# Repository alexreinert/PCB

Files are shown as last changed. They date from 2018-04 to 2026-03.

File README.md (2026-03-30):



Dieses Werk ist lizenziert unter einer [Creative Commons Namensnennung - Nicht-kommerziell - Weitergabe unter gleichen Bedingungen 4.0 International Lizenz](http://creativecommons.org/licenses/by-nc-sa/4.0/).

Bei Nutzung der Platinen freue ich mich über Feedback und kleine Aufmerksamkeiten aus meiner [Amazon Wunschliste](https://www.amazon.de/gp/registry/wishlist/3NNUQIQO20AAP/ref=nav_wishlist_lists_1).

Viele Platinen gibt es auch im offiziellen Shop [viopcb](https://www.viopcb.de/).

# PCB
## HB-RF-ETH
Eine Platine um die Homematic Funkmodule HM-MOD-RPI-PCB und RPI-RF-MOD per Netzwerk anschließen zu können.
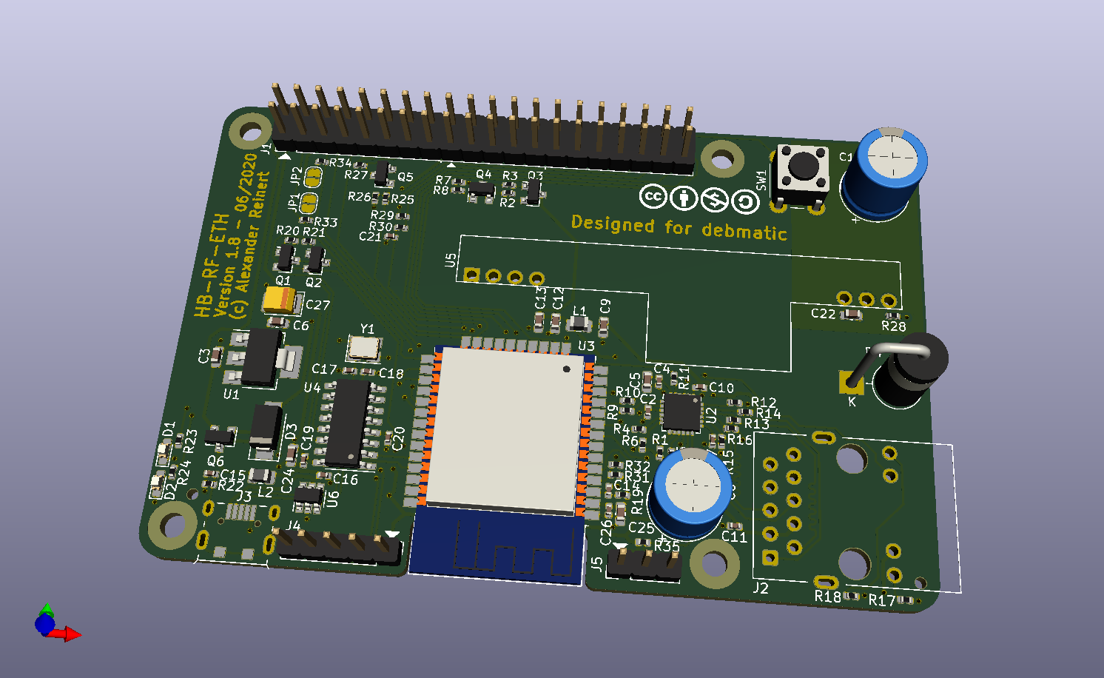
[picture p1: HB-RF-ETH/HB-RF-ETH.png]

[Schaltplan](HB-RF-ETH/HB-RF-ETH.pdf)
Die Platine benötigt spezielle Treiber, welche in [debmatic](https://github.com/alexreinert/debmatic) und in [piVCCU3](https://github.com/alexreinert/piVCCU) verfügbar sind.
Eine passende Firmware findet sich unter [HB-RF-ETH](https://github.com/alexreinert/HB-RF-ETH).
Diese Platine ist auch als fertig bestückter Bausatz erhältlich bei [viopcb](https://www.viopcb.de/produkt/bausatz-hb-rf-eth-mit-poe/).

### Benötigte Bauteile:
Siehe Schaltplan

## HB-RF-USB-2
Eine Platine um die Homematic Funkmodule HM-MOD-RPI-PCB und RPI-RF-MOD per USB anschließen zu können.
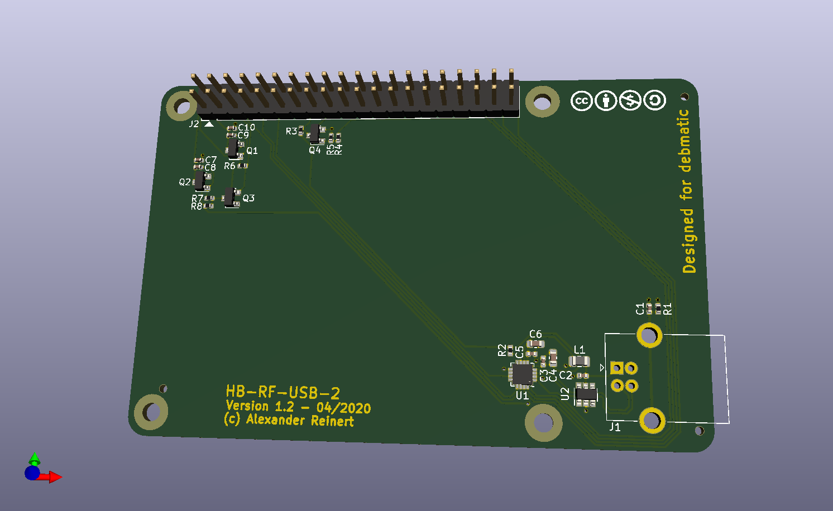
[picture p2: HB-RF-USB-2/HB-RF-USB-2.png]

[Schaltplan](HB-RF-USB-2/HB-RF-USB-2.pdf)
Die Platine benötigt spezielle Treiber, diese sind in [debmatic](https://github.com/alexreinert/debmatic) ab Version 3.51.6-45 und in [piVCCU3](https://github.com/alexreinert/piVCCU) ab Version 3.51.6-40 eingebaut.
Diese Platine ist auch als fertig bestückter Bausatz erhältlich bei [viopcb](https://www.viopcb.de/produkt/bausatz-hb-rf-usb-2/).

### Benötigte Bauteile:
* 1x CP2102N (U1)
* 1x SRV05-4 (U2)
* 2x Kerko 10nF 0402 (C1, C2)
* 6x Kerko 100nF 0402 (C3, C5, C7, C8, C9, C10)
* 2x Kerko 4.7uF 0603 (C4, C6)
* 1x Ferrite Bead 100Ohm, 800mA 0805 (L1)
* 2x AO3401A (Q1, Q2)
* 1x AO3400A (Q3)
* 1x S8050 (Q4)
* 1x Widerstand 1M 0402 (R1)
* 3x Widerstand 1K 0402 (R2, R6, R7)
* 4x Widerstand 10K 0402 (R3, R4, R5, R8)
* 1x USB B Buchse B1HSW6 (J1)
* 1x Pinheader 2x20 (J2)

### EEPROM flashen
[Anleitung](https://hb-programmer.areinert.de)

## HB-RF-USB
Eine Platine um die Homematic Funkmodule HM-MOD-RPI-PCB und RPI-RF-MOD per USB anschließen zu können.
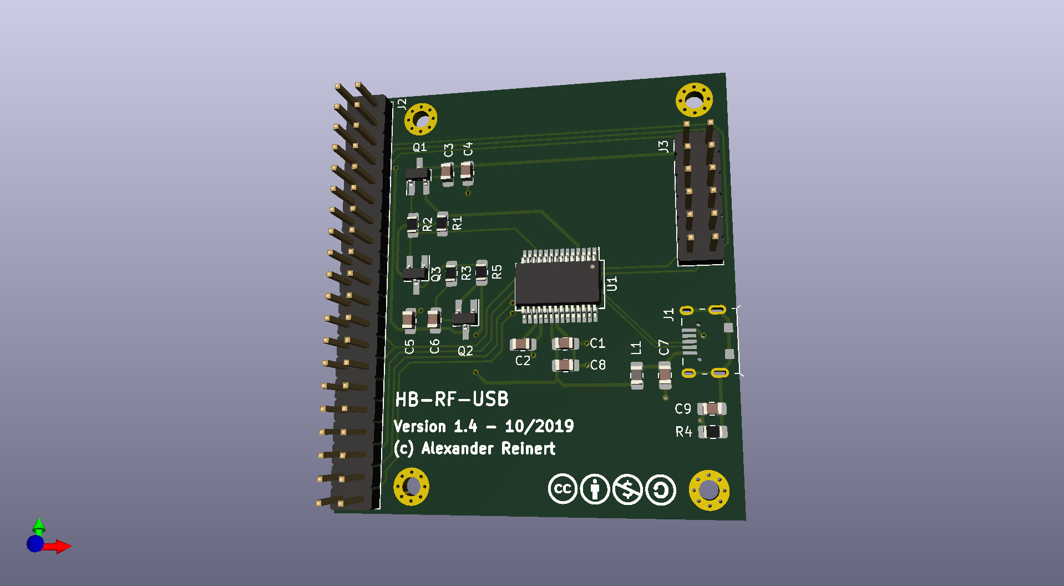
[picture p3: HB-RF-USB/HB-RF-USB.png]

[Schaltplan](HB-RF-USB/HB-RF-USB.pdf)
Die Platine benötigt spezielle Treiber, diese sind in [piVCCU3](https://github.com/alexreinert/piVCCU) ab Version 3.41.11-13, in [debmatic](https://github.com/alexreinert/debmatic) und in [RaspberryMatic](https://github.com/jens-maus/RaspberryMatic) ab Version 3.41.11.20190126 eingebaut.
Diese Platine ist auch erhältlich bei [viopcb](https://www.viopcb.de/produkt/platine-hb-rf-usb/)

### Benötigte Bauteile:
* 1x FTDI FT232RL (U1)
* 1x Micro USB Connector U-F-M5DD-Y-1 (bis Rev. 1.3 MK5P Micro USB Connector)
* 1x Kerko 4.7nF 0805 (C9)
* 1x Kerko 10nF 0805 (C7)
* 6x Kerko 100nF 0805 (C1-C6)
* 1x Kerko 4.7uF 0805 (C8)
* 2x Widerstand 1K 0805 (R2, R3)
* 2x Widerstand 10K 0805 (R1, R5)
* 1x Widerstand 1M 0805 (R4)
* 1x Ferritperle 30 Ohm 0805 (L1)
* 2x IRLML6402 (Q1, Q2)
* 1x IRLML2502 (Q3)
* 1x Pinheader 2*6
* 1x Pinheader 2*20

### EEPROM flashen
[Anleitung](https://hb-programmer.areinert.de)

## HB-UNI-SEN-BATT
Eine universelle Platine für Homebrew Geräte basierend auf [AskSin++ Library](https://github.com/pa-pa/AskSinPP)
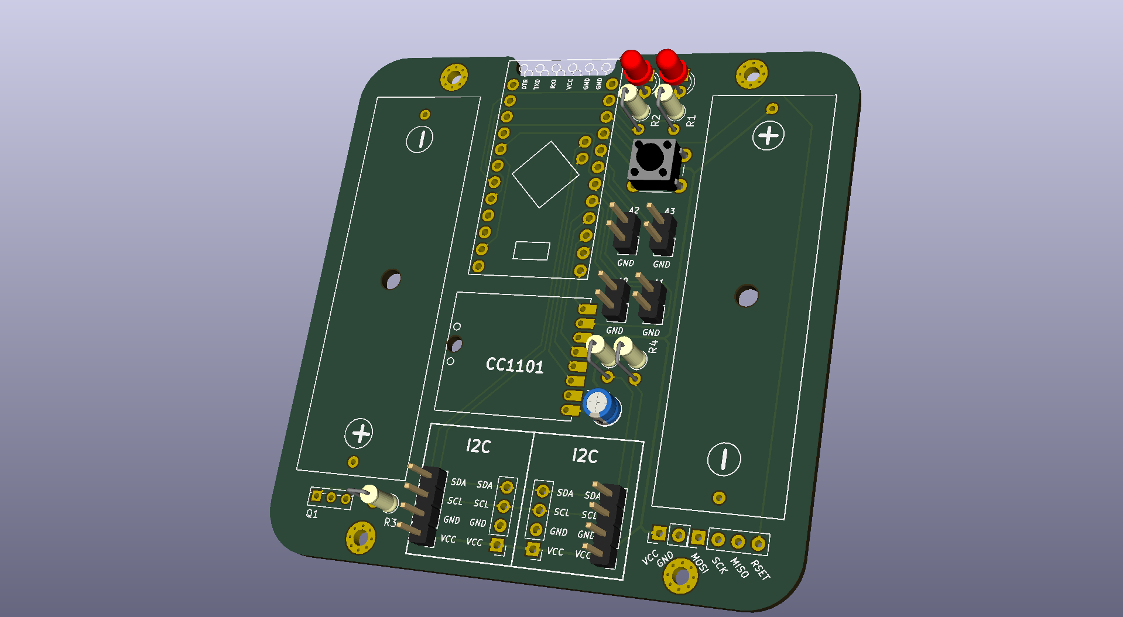
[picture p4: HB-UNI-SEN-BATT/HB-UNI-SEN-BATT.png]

[Schaltplan](HB-UNI-SEN-BATT/HB-UNI-SEN-BATT.pdf)
Diese Platine ist auch erhältlich bei [viopcb](https://www.viopcb.de/produkt/platine-hb-uni-sen-batt/).

### Benötigte Bauteile:
* Arduino Pro Mini 3.3V 8Mhz (The Simple)
* CC1101 Modulplatine 868MHz
* 2x LEDs 3mm Low Current (Pin 4 und 5)
* 2x 470Ohm Widerstände (Vorwiderstand für LEDs)
* Elko 10uF 1,5mm
* 2x Goobay Batteriehalter Mignon Print
* Mikroschalter 6*6mm
* Stiftleiste RM 2mm 1x8 Pin (Für CC1101)
* Stiftleiste RM 2,54MM (nach Bedarf)
* IRLU024N (optional für Verpolungsschutz)
* 100KOhm Widerstand (optional für Verpolungsschutz)
* 2x 10KOhm Widerstand (optional Pullup für I2C)

### Passendes Gehäuse
* Camdenboss CBRS01SWH und CBRS01VWH

### Hinweise
* Achtung: Kein Überspannungschutz vorhanden
* Der Verpolungsschutz ist optional. Dafür Bauteil Q1 (IRLU024N) und R3 (100KOhm Widerstand) bestücken. Alternativ J8 auf der Platinenrückseite brücken um ohne Verpolungsschutz zu arbeiten.

## HB-UNI-SEN-PCB
Eine universelle Platine für Homebrew Geräte basierend auf [AskSin++ Library](https://github.com/pa-pa/AskSinPP)
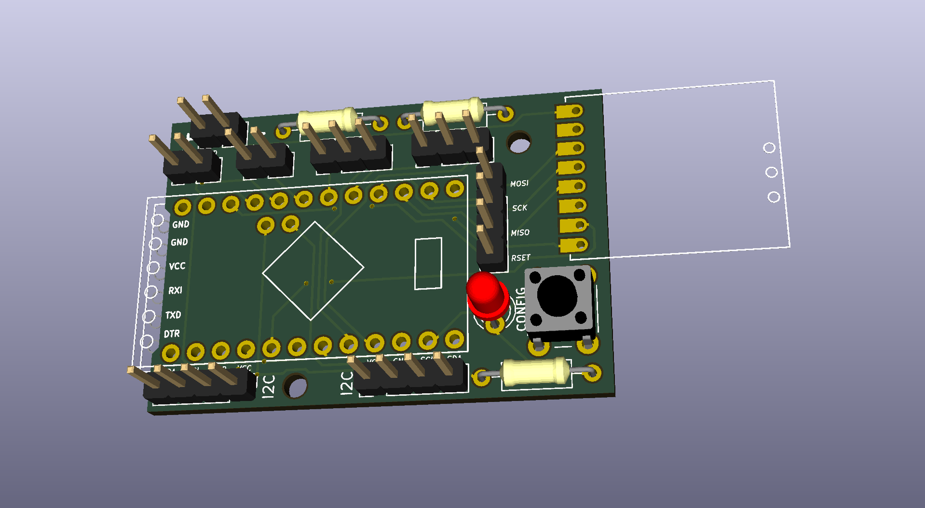
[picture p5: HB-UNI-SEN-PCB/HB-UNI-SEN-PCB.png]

[Schaltplan](HB-UNI-SEN-PCB/HB-UNI-SEN-PCB.pdf)
Diese Platine ist auch erhältlich bei [viopcb](https://www.viopcb.de/produkt/platine-hb-uni-sen-pcb/).

### Benötigte Bauteile:
* Arduino Pro Mini 3.3V 8Mhz (The Simple)
* CC1101 Modulplatine 868MHz
* 1x LEDs 3mm Low Current (Pin 4)
* 1x 470Ohm Widerstände (Vorwiderstand für LEDs)
* Mikroschalter 6*6mm
* Stiftleiste RM 2mm 1x8 Pin (Für CC1101)
* Stiftleiste RM 2,54MM (nach Bedarf)
* Optional: 2x 10KOhm Widerstand und 2x 10KOhm PTC (Temperaturmessung mit PTC an A0 und A1)

### Hinweise
* Achtung: kein Verpolungs- oder Überspannungschutz vorhanden
* Am I2C sind keine Pullups vorhanden, da diese im Regelfall auf I2C Platinen bereits integriert sind
* Aktuell fehlt noch ein Kondensator am VCC vom CC1101.

## HB-UNI-644 (Rev. 2)
Eine universelle Platine für Homebrew Geräte basierend auf [AskSin++ Library](https://github.com/pa-pa/AskSinPP) und dem ATmega644PA
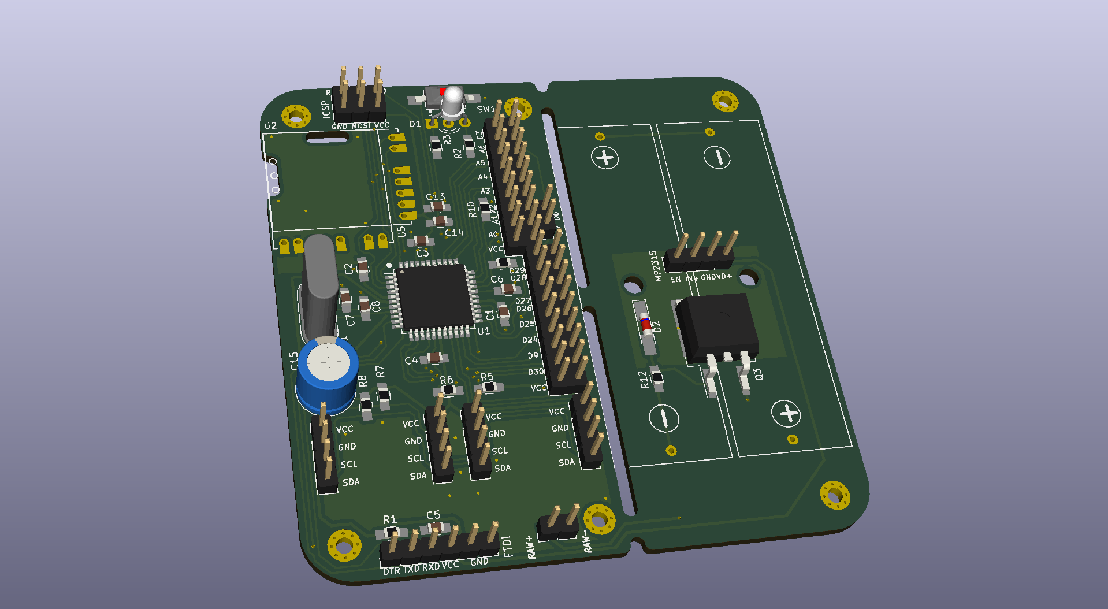
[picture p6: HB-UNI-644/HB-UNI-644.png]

[Schaltplan](HB-UNI-644/HB-UNI-644.pdf)
Diese Platine ist auch erhältlich bei [viopcb](https://www.viopcb.de/produkt/platine-hb-uni-644-rev-2/).

### Benötigte Bauteile:
#### Grundfunktion
* ATmega644PA oder ATmega1284P (TQFP44) (U1)
* CC1101 Modulplatine 868MHz ggf. mit RM 2.0 Pinheader (U2)
* 1x Kerko 10uF 0805 (C13)
* 7x Kerko 100nF 0805 (C1-C6, C14)
* 2x Widerstand 330 Ohm 0805 (R2, R3)
* 1x Widerstand 10K Ohm 0805 (R1)
* 1x Triple Color LED Common Cathode THT (D1)
* 1x Tactile Switch 2 Pin 6x3.5 SMD (SW1)
* 1x Quarz 8 Mhz HC49 THT (Y1) (optional)
* 2x Kerko 22pF 0805 (C7, C8) (optional für Quarz)
* Pinheader nach Bedarf

#### Power Option 1: Batteriebetrieb mit Step-Up
* 2x Goobay Batteriehalter Mignon Print
* 1x Widerstand 470K Ohm 0805 (R5)
* 1x Widerstand 100K Ohm 0805 (R6)
* 1x MAX1724EZK33 (U3)
* 1x LQH43CN100K03L (L1)
* 1x Kerko 10uF 0805 (C9)
* 1x Kerko 33uF 1206 (C10)
##### Verpolungsschutz und Überlastschutz
* 1x IRLML6244 (Q1)
* 1x Widerstand 100K Ohm 0805 (R4)
* 1x PTC 6V/250mA 1206 (F1)

#### Power Option 2: Externe Stromversorgung mit 5-9V, 100mA
* 1x HT-7533-1 (U4)
* 1x Kerko 10uF 50V 1206 (C11)
* 1x Kerko 10uF 0805 (C12)
* 1x Elko 1000uF 8mm*12mm (C15)
##### Verpolungsschutz und Überlastschutz
* 1x IRLML5203 (Q2)
* 1x Widerstand 100K Ohm 0805 (R11)
* 1x PTC 16V/250mA 1206 (F1)

#### Power Option 3: Externe Stromversorgung 5-24V, 1A
* 1x [MP2315 Power Module](https://de.aliexpress.com/item/DC-DC-R-cktritt-Abw-rtswandler-Einstellbar-4-5-V-24-V-zu-5-V-3A/32833398745.html)
   Kontakt zum Trimmer durchtrennen, Lötbrücke bei 3.3V anbringen
* 1x Elko 1000uF 8mm*12mm (C15)
##### Verpolungsschutz und Überlastschutz
* 1x IRF4905S (Q3)
* 1x Widerstand 100K Ohm 0805 (R12)
* 1x Zener 16V MiniMelf (D2)
* 1x PTC 30V/2A 1206 (F1)

#### I2C Pullup Widerstände (optional)
* 2x Widerstand 10k Ohm 0805 (R7, R8)

#### Vorwiderstände für NTC Messung an A0 und A1
* 2x Widerstand 10k Ohm 0805 (R9, R10)

### Passendes Gehäuse
* Camdenboss CBRS01SWH und CBRS01VWH

### Betrieb mit 5V, 16MHz bei Netzbetrieb
* Der MC kann auch mit 5V und dann mit 16MHz betrieben werden, dafür müssen ggü. oben folgende Anpassungen gemacht werden:
* Nicht möglich bei Power Option 1
* Bei Power Option 2: HT-7550-1 statt HT-7533-1 uf U4, Eingangsspannung >= 6V
* Bei Power Option 3: Lötbrücke auf MP2315 Modul bei 5V statt bei 3.3V, Eingangsspannung >= 6V
* CC1101 auf Position U5 statt auf U2
* Nicht bestücken: C13, C14
* Quarz Y1 mit 16MHz statt 8MHz
* Zusätzliche Bauteile
   * 1x LM-3480-3.3 (U6)
   * 1x TXS0108EPWR (U7)
   * 3x Kerko 10uF 0805 (C16, C18, C19)
   * 3x Kerko 100nF 0805 (C17, C20, C21)
* ACHTUNG: Alle VCC Pins laufen dann auf 5V, auch z.B. die vom I2C

### Hinweise
* Auch wenn die meisten Bauteile SMD sind, so ist die Platine für Handlötung entwickelt. Dementsprechend sind alle Teile mind. 0805 mit vergrößerten Pads für Handlötung.
* Es darf immer nur eine Power Option genutzt und bestückt werden
* Die rechte Seite der Platine kann entfernt werden, wenn die Batteriehalter oder das MP2315 Power Module nicht benötigt werden, es laufen keine Leiterbahnen rechts der Fräsung (abgesehen von denen für die Batterie bzw. Power Module)
* Die Lötbrücke J2 muss immer geschlossen werden, außer es wird der Verpolungsschutz für Batteriebetrieb verwendet
* Falls eine externe Spannung von 3.3V ohne Spannungsanpassung, Verpolungsschutz und Überlastschutz verwendet werden soll, dann muss die Lötbrücke J4 geschlossen werden
* Die Anschlüsse an J9 sind zusammen mit J12 genau passend für die Platine CJMCU-2803 um an den Anschlüssen ein Darlington Array zu verwenden (Jeder der Ports ist dann mit 500mA belastbar)
* Beschriftung der Anschlüsse folgt dem Bobuino Pinout

## HB-UNI-SEN-WEA
Eine passende Platine für den [Wettersensor von Jérôme](https://github.com/jp112sdl/HB-UNI-Sen-WEA/)
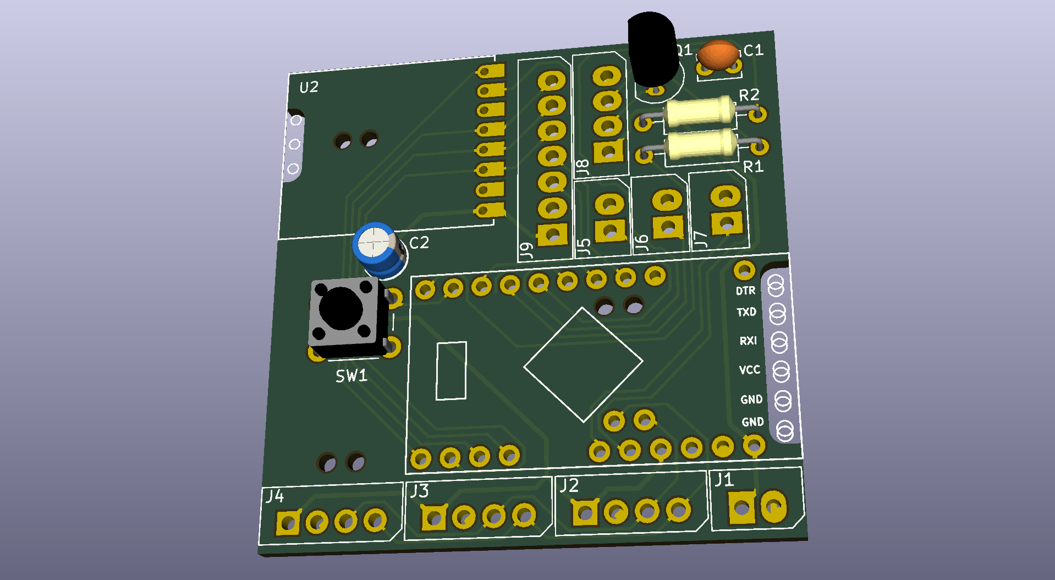
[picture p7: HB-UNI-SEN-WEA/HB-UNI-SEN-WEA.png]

[Schaltplan](HB-UNI-SEN-WEA/HB-UNI-SEN-WEA.pdf)
Diese Platine ist auch erhältlich bei [viopcb](https://www.viopcb.de/produkt/platine-hb-uni-sen-wea/).

### Benötigte Bauteile:
* Arduino Pro Mini 3.3V 8Mhz (The Simple)
* CC1101 Modulplatine 868MHz
* Elko 10uF 1,5mm
* Mikroschalter 6*6mm
* Kerko 1nf RM 2.5mm
* 10K Widerstand
* 100K Widerstand
* MPSA13 TO-92
* 4x Molex Spox 2-pol (Alternativ Stiftleiste oder Kabel direkt anlöten)
* 4x Molex Spox 4-pol (Alternativ Stiftleiste oder Kabel direkt anlöten)
* 1x Molex Spox 7-pol (Alternativ Stiftleiste oder Kabel direkt anlöten)
* Stiftleiste RM 2mm 1x8 Pin (Für CC1101)

### Hinweise
* Achtung: kein Verpolungs- oder Überspannungschutz vorhanden
* Am I2C sind keine Pullups vorhanden, da diese im Regelfall auf I2C Platinen bereits integriert sind

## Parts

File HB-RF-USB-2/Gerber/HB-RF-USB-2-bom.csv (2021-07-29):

Comment | Designator | Footprint | LCSC
10nF | C2,C1 | Capacitor_SMD:C_0402_1005Metric | C15195
4.7uF | C6,C4 | Capacitor_SMD:C_0603_1608Metric | C19666
100nF | C8,C7,C9,C10,C5,C3 | Capacitor_SMD:C_0402_1005Metric | C1525
USB_B | J1 | Connector_USB:USB_B_OST_USB-B1HSxx_Horizontal
Conn_02x20_Odd_Even | J2 | Connector_PinHeader_2.54mm:PinHeader_2x20_P2.54mm_Vertical
Ferrite Bead | L1 | Inductor_SMD:L_0805_2012Metric | C1015
AO3401A | Q2,Q1 | Package_TO_SOT_SMD:SOT-23 | C15127
AO3400A | Q3 | Package_TO_SOT_SMD:SOT-23 | C20917
S8050 | Q4 | Package_TO_SOT_SMD:SOT-23 | C2146
1M | R1 | Resistor_SMD:R_0402_1005Metric | C26083
1K | R7,R6,R2 | Resistor_SMD:R_0402_1005Metric | C11702
10K | R8,R4,R5,R3 | Resistor_SMD:R_0402_1005Metric | C25744
CP2102N | U1 | Package_DFN_QFN:SiliconLabs_QFN-20-1EP_3x3mm_P0.5mm | C89049
SRV05-4 | U2 | Package_TO_SOT_SMD:SOT-23-6 | C85364

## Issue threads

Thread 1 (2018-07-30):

Elko für HB-UNI-SEN-PCB

Hasenpups, 2018-07-30:
Hallo,

Im Schaltplan ist ein 10µF Kondensator eingezeichnet und in der Übersicht schreibst du: Elko 100uF 1,5mm
Was empfiehlst du denn? Hast du vielleicht einen Link für einen passenden Kondensator, ich konnte jetzt keinen mit 1,5mm RM finden.

Danke
Stefan

Closed 2018-07-30.

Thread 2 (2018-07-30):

HB-UNI-SEN-BATT

Hasenpups, 2018-07-30:
Hallo,

Leider sind 3 Leiterbahnen vom CC1101 mit der Massefläche auf der Rückseite der Platine verbunden. Dadurch kann der CC1101 nicht richtig vom Arduino angesprochen werden.
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

Ich denke der Fehler ist passiert als du unten die Pins für das flashen des Bootloaders hinzugefügt hast.

alexreinert, 2018-07-30:
Hhm, ich habe die Platinen hier liegen und da ist das nicht der Fall. Auch die Lötstoppfreistellung zwischen den Pins vom Arduino sieht sehr befremdlich aus und das habe ich so noch nie gesehen. Ich fürchte fast, dass da mit git irgendwas falsch zusammengemerged wurde. Schau ich mir mal an, sobalb ich wieder an meinem Rechner bin.

Hasenpups, 2018-07-30:
Hab die Dateien mal bei dirtypcb und jlcpcb rendern lassen. Sieht bei beiden identisch aus.
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
Ich hab die Bahnen jetzt mal mit einem Cuttermesser getrennt und jetzt kann auch der CC1101 und der BME280 korrekt angesprochen werden.

Closed 2018-07-30.

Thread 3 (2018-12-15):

Platine kaufen

capitaenz, 2018-12-15:
Hallo Alex,

kann man die Platine (HB-UNI-SEN-BATT) von dir irgendwo kaufen? Und wenn ja zu welchem Preis?

VG
Leif

alexreinert, 2018-12-15:
Meld dich per Mail bei mir: alex@areinert.de

Vg Alex

Closed 2018-12-15.

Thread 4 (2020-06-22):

Info bzgl. weitere Platinen

LeelooDallas-github, 2020-06-22:
Wow, schöne Sachen die Du hier gebaut hast.
Ggf. ist in dieser Ecke auch was für Dich dabei.
https://forum.fhem.de/index.php/topic,73954.0.html

CU Leeloo

alexreinert, 2020-06-22:
Danke für die Info, die sind mir bereits bekannt. Das hier ist einfach die Sammlung meiner Platinen und erhebt nicht den Anspruch einer Übersicht aller für HM verfügbaren Platinen, wie sie z.B. auf asksinpp.de gepflegt wird.

Closed 2020-06-22.

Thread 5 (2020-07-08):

HB-RF-USB-2 question

KrX3D, 2020-07-08:
hello,

i have got an HM-MOD-RPI-PCB , can i also use it on my nas where i have unraid running and iobroker in docker? or can it only be run with raspberry?

alexreinert, 2020-07-08:
This is just a pcb. If piVCCU or debmatic and the matching kernel are running on your nas, depends on your nas, but you gave no information about it.

KrX3D, 2020-07-09:
hi, my nas (hardware) is self made. and it is running unraid:

https://unraid.net/

if im not mistaken its linux based.
on it im running several docker images like iobroker etc.

do you know it it is possible to run piVCCU or debmatic with an docker image or virtual machine?

thanks in advance

alexreinert, 2020-07-09:
Docker is not supported, as there is the need to load and access special kernel modules, which is not possible inside a docker container.
(Real) VMs like kvm are supported. piVCCU does only support ARM/ARM64 hardware, debmatic support both x64 and ARM.

KrX3D, 2020-07-09:
ok thanks for the info, if i get it running somehow i will post it here, so others can profit from it.

Closed 2020-07-20.

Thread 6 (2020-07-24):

Clarification: Ferrite Bead

dersimn, 2020-07-24:
> - 1x Ferrite Bead 100Ohm, 800mA 0805 (L1)

Really 100 Ω? Not 100 *m*Ω?
Can you recommend a specific part? Maybe from Reichelt, Aliexpress, Farnell?

alexreinert, 2020-07-24:
100 Ohm is correct. This is not the DC resistance, it is the resistence for high frequencies. A possible part would be https://m.de.aliexpress.com/item/4000444822616.html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

dersimn, 2020-07-25:
Ah, yeah makes sense. Thank you!

Closed 2020-07-25.

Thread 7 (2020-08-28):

Reset vs. ^Reset

dersimn, 2020-08-28:
Wieso erhalten beide Aufsteckboards (HM-MOD-RPI-PCB und RPI-RF-MOD) bei der **HB-RF-USB** das selbe Signal (jeweils Pin 12, 35) während das Signal bei der **HB-RF-USB-2** invertiert wird?

## HB-RF-USB
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

## HB-RF-USB-2
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

alexreinert, 2020-08-28:
Das RPI-RF-MOD invertiert das Reset Signal. Das ist mir bei der HB-RF-USB aber erst aufgefallen, nachdem ich den ersten Hardware Prototypen hatte. Der FT232RL bei der HB-RF-USB kann aber im Zustand Floating bleiben, in welchem sowohl das RPI-RF-MOD, als auch das HM-MOD-RPI-PCB die Reset Leitung selbständig in den richtigen Zustand ziehen um nicht im Reset zu sein. Zum Reseten kann man aber einfach einmal kurz auf High und auf Low gehen und danach wieder auf Floating und damit können beide Module zuverlässig resettet werden.
Der CP2102N vom HB-RF-USB-2 kann nicht in den Zustand Floating gebracht werden, daher muss für eines der beiden Module eine Invertierung vorgenommen werden und doppelte Invertierung für das RPI-RF-MOD fand ich doof, so dass jetzt beide Module einmal invertiert werden.

Closed 2020-08-28.

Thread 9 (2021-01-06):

Is HB-RF-USB-2 compatible with RaspberryMatic?

Denis1983, 2021-01-06:
Hello,

HB-RF-USB is compatible with RaspberryMatic, but HB-RF-USB-2?
Is the driver included in RaspberryMatic?

Regards,
Denis

alexreinert, 2021-01-06:
This is not the RaspberryMatic issue tracker.

Closed 2021-01-06.

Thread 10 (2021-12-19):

LEDs with HM-MOD-UART

frank-f, 2021-12-19:
Hi!

I'm trying to design a PCB based on your HB-RF-USB. I don't need compatibility with RPI-RF-MOD and I want to achieve a more compact form factor. What I would be interested in is the three LEDs of RPI-RF-MOD. As far as I understand, I could just add a few LEDs to my board, right? All I'd need to know is, if they're connected to VCC or Ground on the other side. Unfortunately in all RPI-RF-MOD pictures I could find the area is covered by a sticker, so I don't know where the traces end. Also looking at the FT232RL template was no help, since these lines are configured as I/O. Can you tell me how to connect the LEDs?
Also while looking over closed issues here, I found that the reset line should have been inverted - would it make sense to do that in my board or would that break compatibility with the driver you're using in piVCCU?

Thank you!

frank-f, 2021-12-21:
I dug further and I think the FTDI chip is pulling the lines low to enable the LEDs. Can you confirm that?

I still don't know if I should adapt the inverted RESET line.

alexreinert, 2021-12-21:
Your idea will not work as rhe LEDs are only driven if there is a RPI-RF-MOD is available.
Regarding the form factor: Maybe the HmIP-RFUSB (Non Telekom version) would be the right solution for you, it has now support for BidCos/HmIP dual mode, too.
If you proseed with your own pcb, please use a different USB ID, the USB ID in the template is registered to me and dedicated for my PCB.

frank-f, 2021-12-21:
Too bad about the LEDs. I didn't know about HmIP-RFUSB yet. It does look interesting - if it can do HM and HMIP, the difference to my own PCB would just be an SMA connector. Maybe I'll pursue in that direction.
In case I'll have a PCB produced, would piVCCU even still recognize when using a different USB ID?

alexreinert, 2021-12-21:
The HmIP-RFUSB was only able to communicate using HmIP until the last month. But eQ-3 released a new firmware, that supports both, HM (BidCos) and HmIP. Support for that is included in the current piVCCU testing release, which will hopefully be released as stable in the next days. Soldering a pigtail with SMA connector to it, is possible, too. (Of course you loose the original CE certification and guarantee in that case)
The different USB ID would not be recognized. But I can add the USB ID to the kernel modules, if you are respect the license of the HB-RF-USB and publish the PCB under CC BY-NC-SA 4.0 license.

frank-f, 2021-12-21:
> Soldering a pigtail with SMA connector to it, is possible, too. (Of course you loose the original CE certification and guarantee in that case)

Well my current solution is a modified HM-MOD-UART as well. I guess, I don't have any warranty on that either. 😇
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

> The different USB ID would not be recognized. But I can add the USB ID to the kernel modules, if you are respect the license of the HB-RF-USB and publish the PCB under CC BY-NC-SA 4.0 license.

That would be awesome. Could you also enable the LEDs for that USB ID or is that more complicated?
Of course, the source files will be published under the same license - wether I'll have it produced in the end or not.

alexreinert, 2021-12-21:
Yes, this more complicated, as this is partly in the closed source binaries of eQ-3.

frank-f, 2021-12-21:
Ah, too bad. I'll keep them in the board schematic, but leave them unpopulated then. Or maybe I'll use them as RXLED and TXLED or something.

frank-f, 2022-01-26:
> The different USB ID would not be recognized. But I can add the USB ID to the kernel modules, if you are respect the license of the HB-RF-USB and publish the PCB under CC BY-NC-SA 4.0 license.

It took a little while longer because I was waiting on the USB PID, some parts and also I first started designing it into an 1551USB3 case, but then noticed that it should also fit into a smaller version.

I am not sure if all (or any?) of the mosfets are needed. I think, two were not needed for my project, so I left those out. I kept the one that seems to switch the HM-MOD-UART 3.3V line on and off. Does it work like that with your driver?

I named it [HM-1551USB2](https://github.com/frank-f/HM-1551USB2).

frank-f, 2022-04-01:
@alexreinert I decided to order a small batch of my PCBs. Can you add my VID/PID to piVCCU or can easily I do that myself somehow? I'd like to test if my design working. Thank you in advance. :)

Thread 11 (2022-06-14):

Synology DSM 7.1-42661 lässt den Zugriff aus einer VM auf das Modul per USB nicht mehr zu

Schlumpel, 2022-06-14:
Habe den HB-RF-USB-TK an einer Raspberrymatic-OVA als Virtuelle Maschine sauber betreiben können. Seit DSM 7.1-42661 weigert sich die Raspberrymatic mit angestecktem Modul zu starten, bei einem Start der VM mit abgezogenem Modul klappt der Start, beim nachträglichen Einstecken und Aktivieren des Moduls passiert aber nichts mehr...
Bin ratlos. Der Synology Support ist angeschrieben, lässt aber noch auf sich warten.

Danke für Unterstützung

alexreinert, 2022-06-15:
Sorry, ich kann weder für Synology, noch für RaspberryMatic, noch für die kommerzielle Version der Platine Support leisten.
Im Zweifel im RaspberryMatic Github ein Issue aufmachen oder im Homematic Forum nachfragen, ob jemand eine Idee hat.

Closed 2022-06-15.

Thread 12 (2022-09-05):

HB-RF-USB / 0x6F70 unter Windows erneut flashen ?

Newbie-2, 2022-09-05:
Unter Windows wird die Hardware als HB-RF-USB / Port_#0005.Hub_#0002 erkannt.

Aber die Software "FT_Prog" findet den FTDI232 nun nicht mehr, da es ja für das Gerät idProduct: 0x6F70 keinen Windows lizensierten Treiber gibt !

Ein manuelles ändern des Treibers führt zu der Fehlermeldung: "der hashwert für die datei in der angegebenen katalogdatei nicht vorhanden"

Wie kann ich den FTDI232 unter Windows erneut flashen ?

alexreinert, 2022-09-05:
Man kann die Platine unter Windows nicht neu flashen und ich seheauch keinen Grund dafür. Sollte der Flash seine Daten verlieren, dann muss man von einem Totalschaden ausgehen, das ist mir aber bisher noch nie untergekommen.

Newbie-2, 2022-09-05:
Das klingt ja nicht so gut.
Wenn nicht unter Windows, ist den ein erneutes flashen unter Linux möglich ?

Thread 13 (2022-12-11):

Stromverbrauch HB-RF-USB-2

T1mey, 2022-12-11:
Hallo, gibt es Infos wie hoch der zusätzliche Stromverbrauch der Platine ist?

alexreinert, 2022-12-11:
je nach aufgestecktem Funkmodul zwischen 10 und 15mA.

T1mey, 2022-12-11:
Liegen da 5V an ?

Eigentlich simple Frage ..  lohnt es sich ein pi3 abzuschalten und auf einen futro s740 mit HB-RF-USB-2 umzuziehen (den futro setze ich gerade auf) und will nicht unbedingt 2 systeme laufen lassen ...

alexreinert, 2022-12-11:
Die Platine hat die vollständige Beschaltung um ein HM-MOD-RPI-PCB oder ein RPI-RF-MOD per USB anzuschließen und mit debmatic oder piVCCU auf den jeweils unterstützten Platformen zu betreiben. Beim RPI--RF-MOD darf kein externenes Netzteil genutzt werden.
Siehe einfach auch die Vorstellung der Platine im Homematic Forum.

Ob es sich lohnt, muss man selbst entscheiden, auf jeden Fall braucht die Platine deutlich weniger Strom als ein Pi.

Closed 2023-01-09.

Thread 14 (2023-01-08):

HB-RF-USB2 together with SONOFF Zigbee 3.0 Module makes the USB stack go nuts

luzifer84, 2023-01-08:
Hello Alex,
I have a Linux system with Kernel 5.15.0-051500rc7-generic x86_64 up and running where I have OpenHab 3.2 running in a VirtualBox, Homematic - to be more precise debmatic - in another one with a HB-RF-USB2 connected to it. This has been running for quite a while now (okay, Kernel got an update recently). And according to the rule - never change a running system - I decided to get rid of all the Zigbee control units as I did with the Homematic CCU and bought this USB devices (https://www.ebay.de/itm/384875702899?var=652772510813) as suggested to be the best in several forums. Now the trouble began.
When I plugged it in everything at first seemed to work fine. But when I did a reboot all USB devices except the USB hubs vanished from lsusb. dmesg showed up some random disconnects every second for the HB-RF-USB2 device. So I decided to unplug it. All other devices came back to lsbusb. Then I plugged it in again. Everything worked fine. I did this again inluding the reboot. Same behaviour.
When I unplug the SONOFF during the boot - everything is fine.

When everything is plugged in after the boot has finished it looks like this:
Bus 004 Device 003: ID 05e3:0612 Genesys Logic, Inc. Hub
Bus 004 Device 002: ID 0b95:1790 ASIX Electronics Corp. AX88179 Gigabit Ethernet
Bus 004 Device 001: ID 1d6b:0003 Linux Foundation 3.0 root hub
Bus 003 Device 003: ID 8087:0029 Intel Corp. AX200 Bluetooth
Bus 003 Device 006: ID 10c4:ea60 Silicon Labs CP210x UART Bridge --> the SONOFF
Bus 003 Device 005: ID 0403:6f70 Future Technology Devices International, Ltd HB-RF-USB
Bus 003 Device 004: ID 0001:0000 Fry's Electronics MEC0003
Bus 003 Device 002: ID 05e3:0610 Genesys Logic, Inc. Hub
Bus 003 Device 001: ID 1d6b:0002 Linux Foundation 2.0 root hub
Bus 002 Device 001: ID 1d6b:0003 Linux Foundation 3.0 root hub
Bus 001 Device 001: ID 1d6b:0002 Linux Foundation 2.0 root hub

I neither do have any experience whether this configurations works stable over time nor do I have any clue how to get rid of this boot problem. Do you have any suggestions how I could solve this?

Thanks for your time and help in advance.

Greetings,
Torben

luzifer84, 2023-01-09:
Hi,
I just wanted to add some additional pieces of information.
Having both devices plugged in at the same time, devices stop working after a few minutes. I receive the following messages in the host:

Jan  9 05:03:58 firetux-nuc kernel: [21317.321071] usb 3-5-port2: disabled by hub (EMI?), re-enabling...
Jan  9 05:03:58 firetux-nuc kernel: [21317.321467] usb 3-5.2: USB disconnect, device number 5
Jan  9 05:03:58 firetux-nuc kernel: [21317.545497] usb 3-5.2: new full-speed USB device number 7 using xhci_hcd
Jan  9 05:03:58 firetux-nuc kernel: [21317.653805] usb 3-5.2: New USB device found, idVendor=0403, idProduct=6f70, bcdDevice= 6.00
Jan  9 05:03:58 firetux-nuc kernel: [21317.653827] usb 3-5.2: New USB device strings: Mfr=1, Product=2, SerialNumber=3
Jan  9 05:03:58 firetux-nuc kernel: [21317.653837] usb 3-5.2: Product: HB-RF-USB
Jan  9 05:03:58 firetux-nuc kernel: [21317.653843] usb 3-5.2: Manufacturer: Alexander Reinert
Jan  9 05:03:58 firetux-nuc kernel: [21317.653850] usb 3-5.2: SerialNumber: A94YTFKB
Jan  9 05:03:58 firetux-nuc kernel: [21317.969837] usb 3-5.2: reset full-speed USB device number 7 using xhci_hcd
Jan  9 05:03:59 firetux-nuc kernel: [21318.285897] usb 3-5.2: reset full-speed USB device number 7 using xhci_hcd
Jan  9 05:09:34 firetux-nuc kernel: [21654.217259] usb 3-5-port1: disabled by hub (EMI?), re-enabling...
Jan  9 05:09:34 firetux-nuc kernel: [21654.217705] usb 3-5.1: USB disconnect, device number 4
Jan  9 05:09:35 firetux-nuc kernel: [21654.452226] usb 3-5.1: new low-speed USB device number 8 using xhci_hcd
Jan  9 05:09:35 firetux-nuc kernel: [21654.557363] usb 3-5.1: New USB device found, idVendor=0001, idProduct=0000, bcdDevice= 1.00
Jan  9 05:09:35 firetux-nuc kernel: [21654.557370] usb 3-5.1: New USB device strings: Mfr=1, Product=2, SerialNumber=0
Jan  9 05:09:35 firetux-nuc kernel: [21654.557373] usb 3-5.1: Product: MEC0003
Jan  9 05:09:35 firetux-nuc kernel: [21654.557374] usb 3-5.1: Manufacturer: MEC
Jan  9 05:09:35 firetux-nuc kernel: [21654.579145] hid-generic 0003:0001:0000.0002: hiddev0,hidraw0: USB HID v1.00 Device [MEC MEC0003] on usb-0000:00:14.0-5.1/input0
Jan  9 05:09:35 firetux-nuc kernel: [21654.580077] usb 3-5-port2: disabled by hub (EMI?), re-enabling...
Jan  9 05:09:35 firetux-nuc kernel: [21654.580602] usb 3-5.2: USB disconnect, device number 7
Jan  9 05:09:35 firetux-nuc kernel: [21654.804380] usb 3-5.2: new full-speed USB device number 9 using xhci_hcd
Jan  9 05:09:35 firetux-nuc kernel: [21654.912697] usb 3-5.2: New USB device found, idVendor=0403, idProduct=6f70, bcdDevice= 6.00
Jan  9 05:09:35 firetux-nuc kernel: [21654.912721] usb 3-5.2: New USB device strings: Mfr=1, Product=2, SerialNumber=3
Jan  9 05:09:35 firetux-nuc kernel: [21654.912730] usb 3-5.2: Product: HB-RF-USB
Jan  9 05:09:35 firetux-nuc kernel: [21654.912737] usb 3-5.2: Manufacturer: Alexander Reinert
Jan  9 05:09:35 firetux-nuc kernel: [21654.912744] usb 3-5.2: SerialNumber: A94YTFKB
Jan  9 05:09:35 firetux-nuc kernel: [21655.236797] usb 3-5.2: reset full-speed USB device number 9 using xhci_hcd
Jan  9 05:09:36 firetux-nuc kernel: [21655.548702] usb 3-5.2: reset full-speed USB device number 9 using xhci_hcd

Plus these mesages I saw multiple times:
module: x86/modules: Skipping invalid relocation target, existing value is nonzero for type 1, log 8e0437ee, val ffffffffc145fade

alexreinert, 2023-01-09:
Both devices are on the same internal USB Controller (Bus 3). Try on different USB Controllers. Could be an issue with to high power consumption if both sticks are used on a single controller.

luzifer84, 2023-01-09:
I tried but no different result. In fact the last configuration with both devices at the same controller is a configuration where I put both even on an external USB HUB with external 5V 1A power supply. Did not make any difference.

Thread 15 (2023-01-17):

Modul wird nach Neustart nicht erkannt (Stromversorgung?)

DasPflanze, 2023-01-17:
Hallo Herr Reinert,

erstmal vielen Dank für die Entwicklung der verschiedenen Platinen! Allerdings habe ich mit meiner ein kleines Problem. Nach der Erstinstallation funktionierte alles ohne Probleme. Bis zum ersten Neustart meines Servers (Unraid mit RaspberryMatic als VM).

Die Platine wird danach noch korrekt unter lsusb erkannt nur leider bekommt das Modul keinen Strom mehr. An Pin 1 (von der 40 Pin Leiste) liegen dann statt 3,3V nur zwischen 1 und 2V an. Misst man Pin 2, so fängt er meist bei ca. 2,2V an und dann sinkt der Wert relativ zügig bis auf 0V (vermutlich ein Kondensator der sich entlädt). Solange Pin 2 nicht auf 0V ist wird die Platine nicht erkannt. Erst bei 0V und nach einem Neustart der VM lässt sich das Modul wieder nutzen.

Um Probleme mit der VM auszuschließen habe ich das selbe auch an einem Raspberry Pi 4 versucht mit dem selben Ergebnis.

Mein Bauchgefühl sagt mir, dass hier eventuell ein Widerstand (o.ä.) defekt ist. Können Sie da weiterhelfen?

Grüße
Stefan Müller

alexreinert, 2023-01-17:
Sorry, ich kann keinen wirklichen Support für RaspberryMatic geben, da die Implementierung dort nicht der Referenzimplementierung entspricht.
Da es nicht mal eine Angabe gibt, um welche Platine es überhaupt geht, kann ich auch keinen Tipp in Richtung der Lösung geben.

DasPflanze, 2023-01-17:
Ah sorry, das habe ich komplett vergessen...
Es geht um die HB-RF-USB-2 und ich denke nicht, dass es mit RaspberryMatic zusammenhängt. Theoretisch sollte das Modul ja 5V bekommen, selbst wenn man das USB Kabel nur in ein USB-Netzteil Steckt, oder?

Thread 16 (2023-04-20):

HB-RF-USB-2 wird heiß und disconnected mit over-current-condition

viennaa, 2023-04-20:
Hi Alex,

ich wollte mein HB-RF-USB mit dem HB-RF-USB-2 ersetzen. Ich betreibe es mit dem RPI-RF-MOD and einem Intel NUC.

Wenn ich die Platine anstecke, ohne den RPI-RF-MOD verbunden zu haben, wird der Treiber erkannt und alles ist in Ordnung.
Sobald ich sie mit dem RPI-RF-MOD verbunden anstecke, habe ich ständige disconnects im Linux und die Platine wird innerhalb weniger Sekunden sehr warm. Ich habe sie nach ca. 10 Sekunden abgesteckt, damit sie nicht durchbrennt.

```
[756009.049042] usb usb2-port1: over-current condition
[756009.182377] usb 2-2: USB disconnect, device number 97
[756009.439048] usb 2-2: new full-speed USB device number 98 using xhci_hcd
[756009.580818] usb 2-2: New USB device found, idVendor=10c4, idProduct=8c07, bcdDevice= 2.00
[756009.580832] usb 2-2: New USB device strings: Mfr=1, Product=2, SerialNumber=3
[756009.580838] usb 2-2: Product: HB-RF-USB-2
[756009.580843] usb 2-2: Manufacturer: Alexander Reinert
[756009.580847] usb 2-2: SerialNumber: ***
[756009.715710] usb usb2-port1: over-current condition
[756009.849104] usb 2-2: USB disconnect, device number 98
[756010.105747] usb 2-2: new full-speed USB device number 99 using xhci_hcd
[756010.247789] usb 2-2: New USB device found, idVendor=10c4, idProduct=8c07, bcdDevice= 2.00
[756010.247803] usb 2-2: New USB device strings: Mfr=1, Product=2, SerialNumber=3
[756010.247809] usb 2-2: Product: HB-RF-USB-2
[756010.247813] usb 2-2: Manufacturer: Alexander Reinert
[756010.247817] usb 2-2: SerialNumber: ***
```

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

Habe ich eine defekte Platine erhalten oder was mache ich falsch? Ich kann auch keine verbundenen Pins o.Ä. auf der Platine erkennen.

VG

alexreinert, 2023-04-20:
Es ist hoffentlich kein Netzteil am RPI-RF-MOD eingesteckt? Wobei das das Problem erklären könnte, weil da dann u.U. Ströme mit mehreren Ampere fließen könnten.
Ansonsten sieht das schwer nach einem Kurzschluß aus ohne, dass ich ohne Messung sagen könnte, ob dieser auf dem RPI-RF-MOD oder der HB-RF-USB-2 ist, oder ob das Funkmodul nicht korrekt aufgesetzt ist und dadurch eine Verbindung zwischen VCC und Gnd herstellt (komplett falsch rum,  oder um einige Pins verschoben).

Closed 2023-04-20.

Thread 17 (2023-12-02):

HB-RF-ETH nicht mehr erreichbar

vore, 2023-12-02:
Hallo Herr Reinert,

ich habe mir vor einger Zeit die Platine HB-RF-ETH mit POE gekauft. Lag jetzt etwas länger in der Schublade weil ich passende Infrastruktur noch nicht fertig hatte. Jetzt bin ich soweit, aber die Platine ist nicht mehr ansprechebar. Der ESP scheint zu booten (LED grün leuchtet nach kurzer Zeit) an der Steckbuchse leuchtet aber nur eine LED (vermutlich POE).
Hatte beim Kauf die Platine testweise angeschlossen, Firmwareupdates eingespielt und dann erst mal wieder verpackt und zur Seite gelegt, die Funktion war auf jeden Fall gegeben.
Auch ein Werksreset hilft nicht, die Platine ist nicht erreichbar.

Könnte eventuell das Steckmodul defekt sein? POE funktionioniert aber anscheinend noch.
Kann ich etwas prüfen und ggf. tauschen?

Danke!
Grüße  Volker Reinhardt

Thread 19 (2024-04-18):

HB-RF-USB-2 verstorben?

DarthDestroyer, 2024-04-18:
Schönen guten Abend,

ich habe seit August 2021 die HB-RF-USB-2 in Kombination mit dem RPI-RF-MOD erfolgreich betrieben. Alles lief, bis auf Startschwierigkeiten (war wohl nicht geflashed von Smartkram), bisher ohne Auffälligkeiten.

Damals hatte ich mir mit
```
systemctl stop debmatic
detect_radio_module --debug /dev/raw-uart
java -Dgnu.io.rxtx.SerialPorts=/dev/raw-uart -jar /opt/HmIP/hmip-copro-update.jar -p /dev/raw-uart -o -f /firmware/RPI-RF-MOD/dualcopro_update_blhmip-4.2.14.eq3
detect_radio_module --debug /dev/raw-uart
```
helfen können.

Jetzt läuft aber gar nichts mehr! Per USB kommt nur noch Käse, sowohl unter Linux als auch Windows wird rein gar nichts erkannt (Windows steigt aus mit "Fehler bei Identifizierung") und Debian (mit installiertem Debmatic) mit
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

Ist jetzt ein Auszug aus dem dmesg...
RPI-RF-MOD leuchtet "weiß" - Meiner Einschätzung nach

Die Linux Umgebung ist ein Proxmox mit USB Controller komplett durchgeschliffen (PCI) und vorher "nur" mit Port USB Passthrough getestet - Keine Unterschiede!

Unter lsusb nicht aufgelistet...

Kabel hab ich mehrere durch...

Hat ja auch vorher alles einwandfrei funktioniert! Ist im Rack verbaut, die Kombi - Da ist auch nichts mit Runterfallen oder Erschütterung!

Genutzt, hatte ich die Geschichte über Rapsberrymatic als Home-Assistant Addon - ob jetzt Raspberrymatic ein Firmwareupdate "versucht" hat und dabei verkackt hat - weiß ich nicht... Wenn die Hardware nicht verstorben ist, dürfte dies der andere Schuldige sein!

Kann ich noch etwas prüfen oder versuchen?

Vielen Dank und Grüße gehen raus!

alexreinert, 2024-04-19:
Die Meldungen aus dmesg sehen extrem nach Hardware Problem aus. Nachdem das Kabel bereits getauscht wurde, würde ich mal einen kritischen Blick auf die Lötstellen der USB Buchse schauen.

DarthDestroyer, 2024-04-20:
Alles nachgelötet - Lötstellen aus der Hölle aber die Messwerte sahen gut aus!
Danke nochmal, dass du auch die Schaltpläne zur Verfügung stellst - Das hat zum Nachmessen super geholfen!

Auch die Gegenstelle auf dem RPI-RF-MOD nachgelötet...

Leider brachte alles keinen Erfolg:
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

Was ich beim letzten Test jetzt erkannte, die LED blinkt mehrmals kurz rot ca. 5 mal in sehr kurzen Intervallen um anschließend dann (eher) weiß stehen zu bleiben...

Ich vermute, da ist nur noch das Grab zu schaufeln?
Spannung scheint durchzugehen - Sonst würde der RPI-RF-MOD ja gar nichts tun...

alexreinert, 2024-04-20:
Klingt dann leider wirklich nach einem Hardware Defekt.

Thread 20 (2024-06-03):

HB-RF-ETH piVCCU

tonreg44, 2024-06-03:
Ich möchte Homematic in der Synology integrieren und habe mir den kompletten Bausatz gekauft und installiert Ich erreiche die Platine über die iP Adresse, weiß aber nicht wie ich piVCCU installieren kann. Wenn ich mit putty versuche bekomme ich Network error: connection refused. Ich verwende Port 22 und SSH. Was mache ich falsch??

alexreinert, 2024-06-03:
Die Platine ist dafür gedacht um mit ihr ein Funkmodul per Netzwerk an eine piVCCU oder debmatic Installation anzuschließen. Auf ihr selbst kann man kein piVCCU installieren.

tonreg44, 2024-06-08:
ich habe exakt diesen Bausatz. Wird das Funkmodule über die untere Platine mit Strom versorgt?
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

alexreinert, 2024-06-08:
PoE, Micro USB oder über den Anschluss am Funkmodul. Wichtig ist aber, das nur eine der drei Möglichkeiten genutzt wird, da es sonst zu Schäden kommen kann.

tonreg44, 2024-06-10:
Ich muss etwas ausholen um mein Projekt zu beschreiben. Ich habe eine seit langer Zeit laufende Homematik Steuerung mit Raspberry PI und CCU3, läuft seit Jahren, Ziel ist aber homematic auf meiner Synology einzurichten. Dazu habe ich den oben gezeigten Bausatz gekauft. Vorgegengen bin ich nach dem YouTube von Stefan (verdrahtet). Soweit ist alles installiert (Redmatic OVA). Was ich nicht zum Laufen bekomme ist die Verbindung über USB zur Synology. Wenn ich Geräte anlernen möchte erscheint diese Nachricht:
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. Auf das Funkmodule kann ich zugreifen
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
Hier ist der Zusammenbau beschrieben: https://technikkram.net/blog/2020/08/17/endlich-verfuegbar-neue-platine-hb-rf-eth-zusammenbau-und-einrichtung/. Mir ist nicht klar, wie ich das piVCCU image auf die Synology bekomme. Desweiteren kann ich die geforderte "Zusatzsoftware für den HB-RF-ETH support" über putty nicht installieren (sudo apt install hb-rf-eth). Es erscheint diese Nachricht:
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
Für die Unterstützung schon im voraus besten Dank.

alexreinert, 2024-06-10:
Anschluss per USB geht mit der HB-RF-ETH gar nicht, es geht nur die Nutzung per Netzwerk. Es gibt kein Image von piVCCU für die Synology. Das Paket hb-rf-eth muss man auf dem System installieren, auf dem piVCCU (oder debmatic) läuft, nicht auf der HB-RF-ETH Platine. Diese hat keinen Zugang per SSH, sondern nur die Weboberfläche und für die technische Anbindung des Funkmoduls an die Treiber auf der piVCCU/debmatic Installation.

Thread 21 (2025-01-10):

HB-RF-USB-2 wird erkannt / Funkmodul aber nicht

Fepsi91, 2025-01-10:
Hallo,

ich wollte mit meiner Raspberrymatic von einem PI3 auf eine VM auf einem Windows PC wechseln.
Da ich für meine Hausautomatisierung sowieso einen Mini-PC betreibe, liegt es nah auch alle Module hier laufen zu lassen.

Ich habe die VM nach der Anleitung eingerichtet. Nun wird aber das Funkmodul nicht erkannt. Unter lsusb wird der HB-RF-USB-2 auch angezeigt.
Wenn ich das ganze an der PI3 anschließe funktioniert das Funkmodul wie gewünscht.
Ich bin absoluter Linux Neuling, und daher für jede Hilfe dankbar.

Vielen Dank im Voraus !

alexreinert, 2025-01-11:
Sorry, aber für RaspberryMatic kann ich leider keinen Support geben. Bitte dort fragen.

Rossi0209, 2025-01-11:
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

Moin, Du musst natürlich im Hypervisor (keine Ahnung welcher das bei Dir ist, vermutlich VM Workstation oder Proxmox - wäre auch eine hilfreiche Info), den Adapter an die VM hängen.

Ich mache den Virtualisierungskram beruflich mit vielen tausenden Maschinen, woher sollte wohl eine Maschine wissen, dass der Adapter für genau diese Maschine ist?

Schau mal in die Einstellungen der VM (evtl. runterfahren), da gibt es garantiert irgendwo Hardwareeinstellungen wie HDDs, RAM … da ist auch irgendwo USB, ggf. gibt es da auch irgendwo einen Button wo man neue Hardware hinzufügen kann.

Von der Performance wird das aber glaube ich eng auf einem MiniPc. Wenn man das sowieso schon virtualisiert, würde ich zudem auch ein Debian nehmen.

Hoffe das hilft.

Viele Grüße
Marcus

Fepsi91, 2025-01-11:
Moin,

ich arbeite beruflich auch mir Virtualisierungsumgebungen. Bin dann tiefergehend aber eher im SPS Bereich unterwegs.
Die Hardware wird automatisch beim Startup an die VM durchgereicht. In VM-Ware wird das ganz auch als aktiv mit der VM verbunden angezeigt.
Nur bin ich jetzt nicht so bewand in der Raspberrymatic um tiefergehend zu suchen warum hier das Funkmodul nicht erkannt wird.
Hier ein paar Screenshots:
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

Danke für die schnelle Hilfe!

Gruß
Fabian

Rossi0209, 2025-01-11:
Siehst Du denn den Menüpunkt  bzgl. Led?

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

Fepsi91, 2025-01-11:
Ja, den Menüpunkt habe ich

Rossi0209, 2025-01-11:
Dann sollte das Modul doch auch eigentlich erkannt worden sein.

Fepsi91, 2025-01-11:
Leider nicht.

hier noch die Info aus der Raspberrymatic
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

Und auch wenn ich Geräte anlernen möchte kommt ein Hinweis, dass kein Modul erkannt wurde.

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

charlie89, 2025-09-30:
@Fepsi91: Probier doch mal einen USB-Hub zwischen PC und HB-RF-USB-2 zu stecken. Ist egal ob es ein 15 Jahre alter USB 2.0 Hub oder so ein neuer USB-Dongle ist, der aus USB-C mehrere USB-Ports inkl. SD-Kartenleser und HDMI-Ausgang macht.

Denn ich hatte (bis gestern) auf einem Supermicro H12SSL Mainboard auch genau das Problem, dass die HB-RF-USB-2 Platine per lsusb sichtbar war, aber dann von Raspberrymatic nicht erkannt wurde.
Ein `detect_radio_module --debug /dev/raw-uart` hat bei mir gezeigt, dass es Daten sendet aber keine Daten zurückkommen, obwohl grundsätzlich die USB-Verbindung geht. Mit einem USB-Hub dazwischen (sowohl alt als neu) funktionierte es sofort, d.h. der USB-Controller am Mainboard hat da irgendeine Inkompatibilität mit dem HB-RF-USB-2 und hat die Daten einfach verschluckt. Und das Problem tritt auf allen 4 USB-Ports auf dem Mainboard auf, obwohl 2 Ports direkt in die CPU gehen und 2 Ports über einen ASM1042 USB->PCIe Controller angebunden sind.
Die USB-Hubs dürften weniger Bugs haben als die in Mainboard/CPU verbauten USB-Controller...

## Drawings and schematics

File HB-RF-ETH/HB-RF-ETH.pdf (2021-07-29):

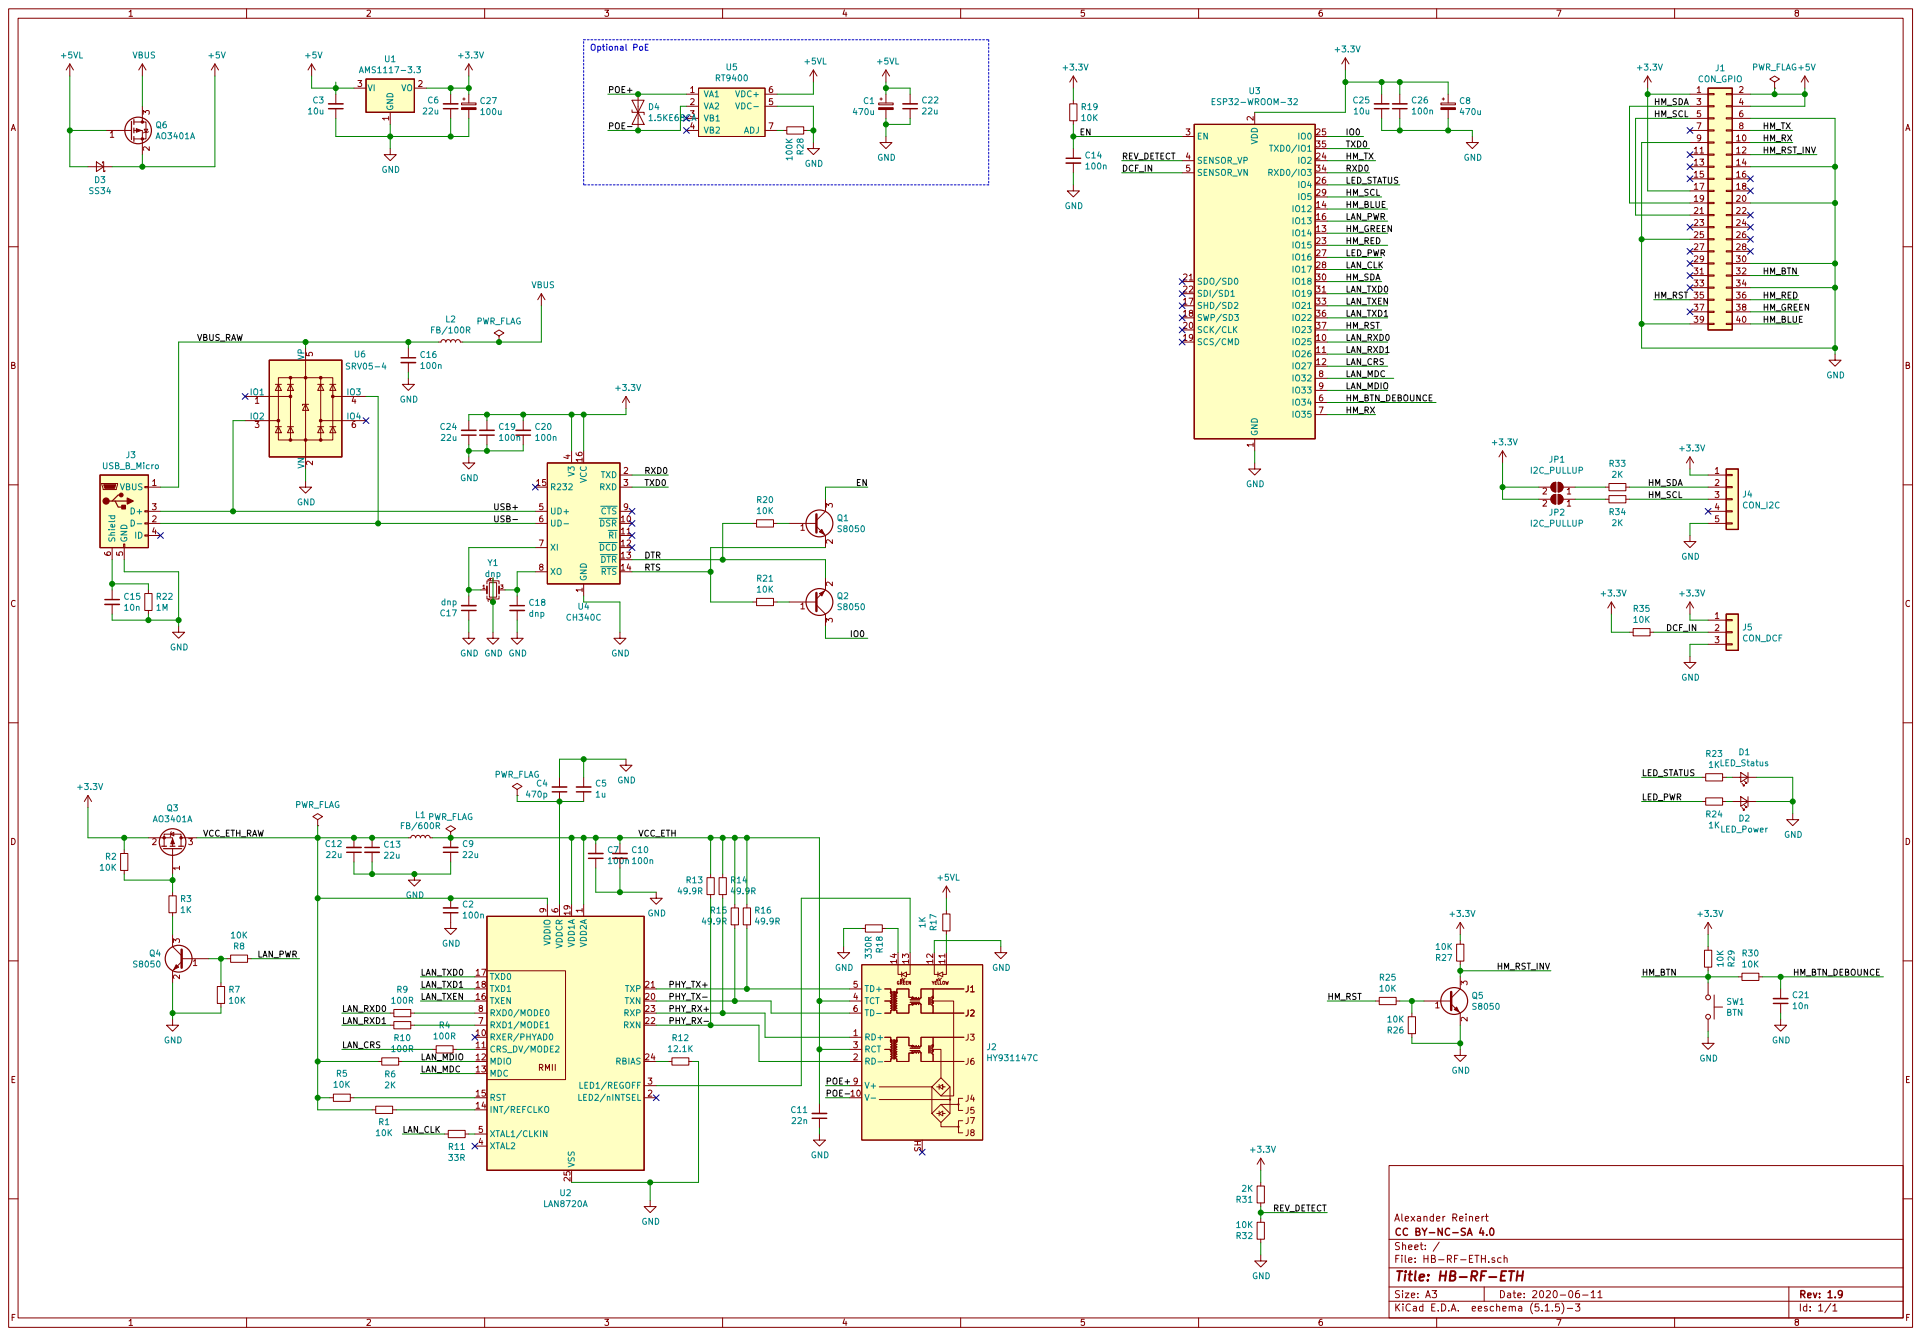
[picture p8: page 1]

2 SCK/CLK 20 SDO/SD0 21 SDI/SD1 22
HM_TX HM_RX HM_RST

21 | 22
23 | 24

1 DSR 10 RI 11 DCD 12 DTR 13 RTS 14 R232 15 VCC 16 TXD 2 RXD 3 V3

4 UD+ 5 UD- 6 XI 7 XO 8 CTS 9 U4 CH340C

File: HB-RF-ETH.sch Sheet: / CC BY-NC-SA 4.0 Alexander Reinert

Id: 1/1 Title: HB-RF-ETH

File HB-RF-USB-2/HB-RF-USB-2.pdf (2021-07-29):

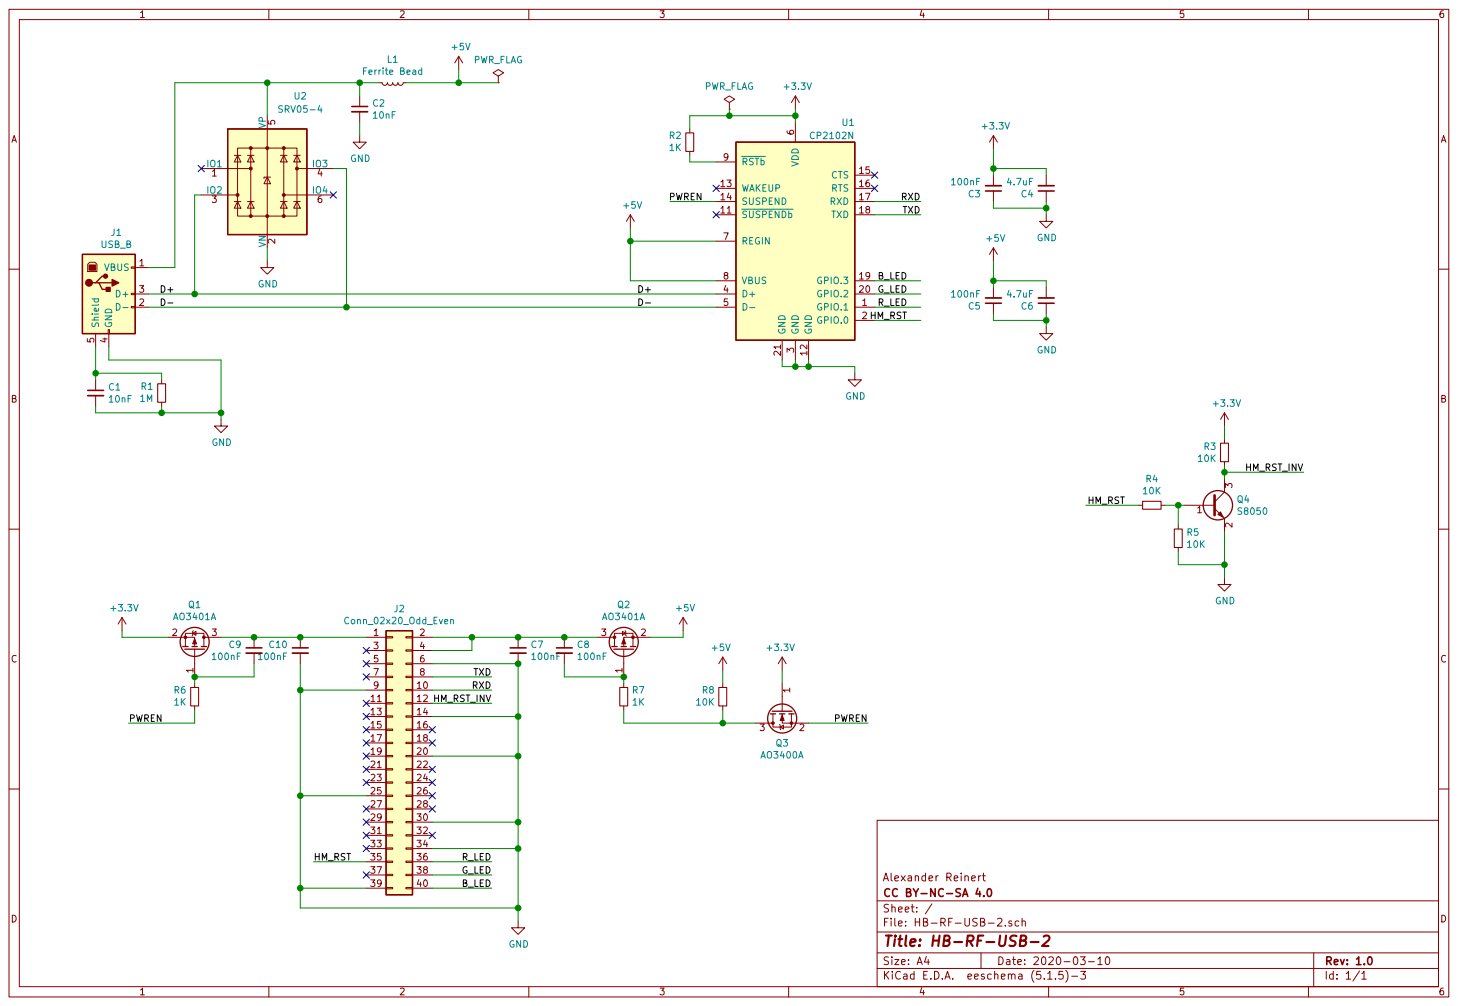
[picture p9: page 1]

File: HB-RF-USB-2.sch Sheet: / CC BY-NC-SA 4.0 Alexander Reinert R7

Id: 1/1 Title: HB-RF-USB-2

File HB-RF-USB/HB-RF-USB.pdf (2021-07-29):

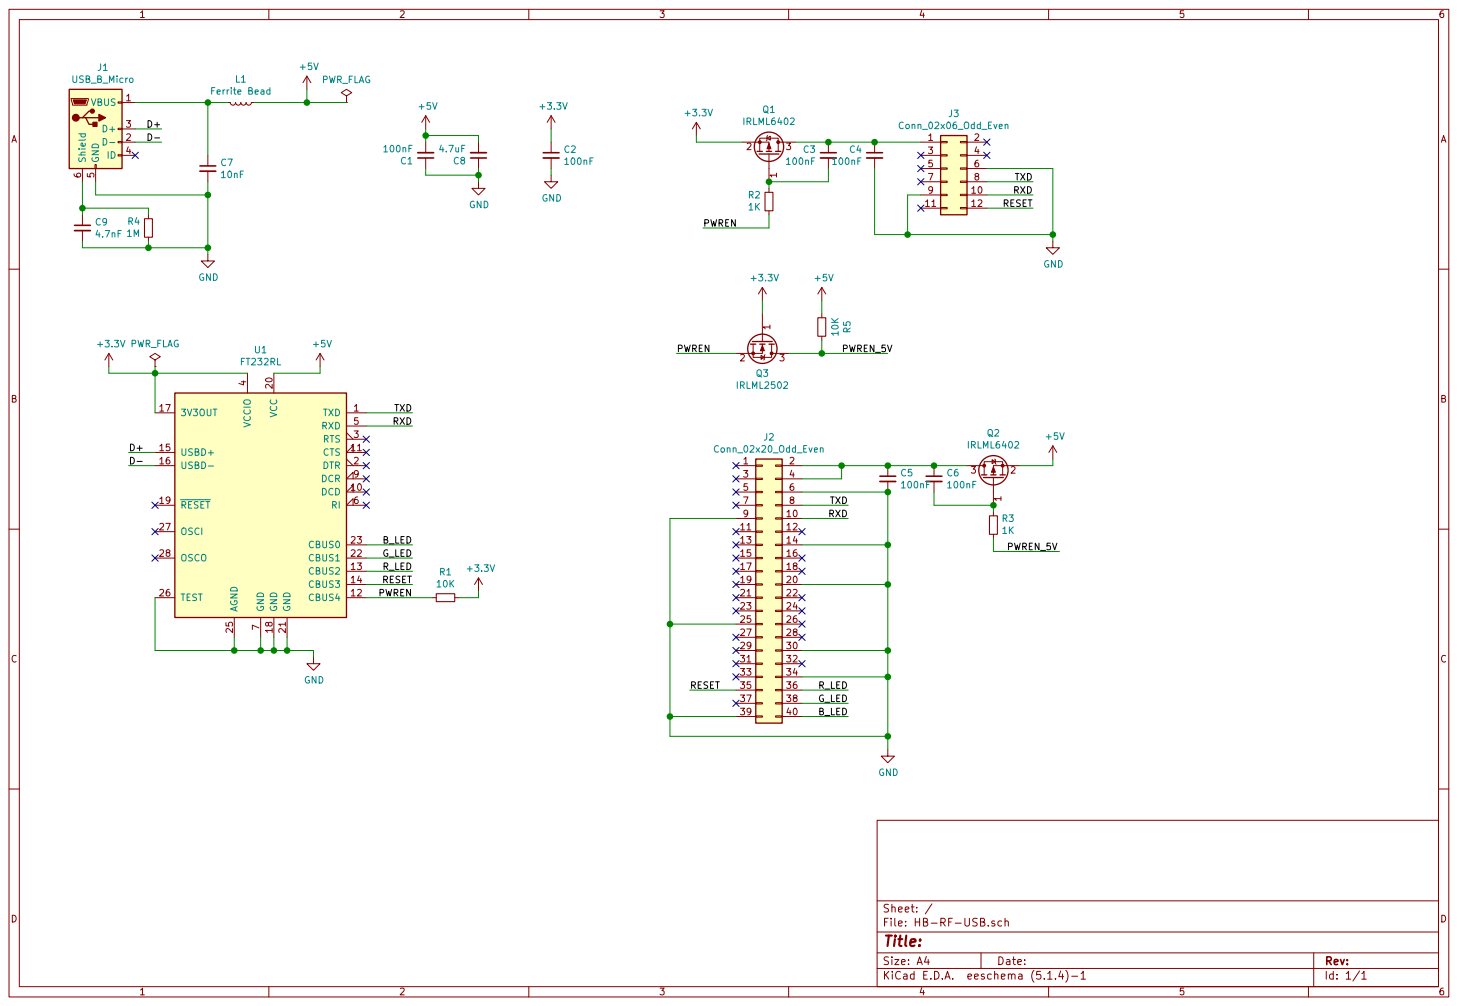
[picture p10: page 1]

Id: 1/1 Title: File: HB-RF-USB.sch Sheet: /

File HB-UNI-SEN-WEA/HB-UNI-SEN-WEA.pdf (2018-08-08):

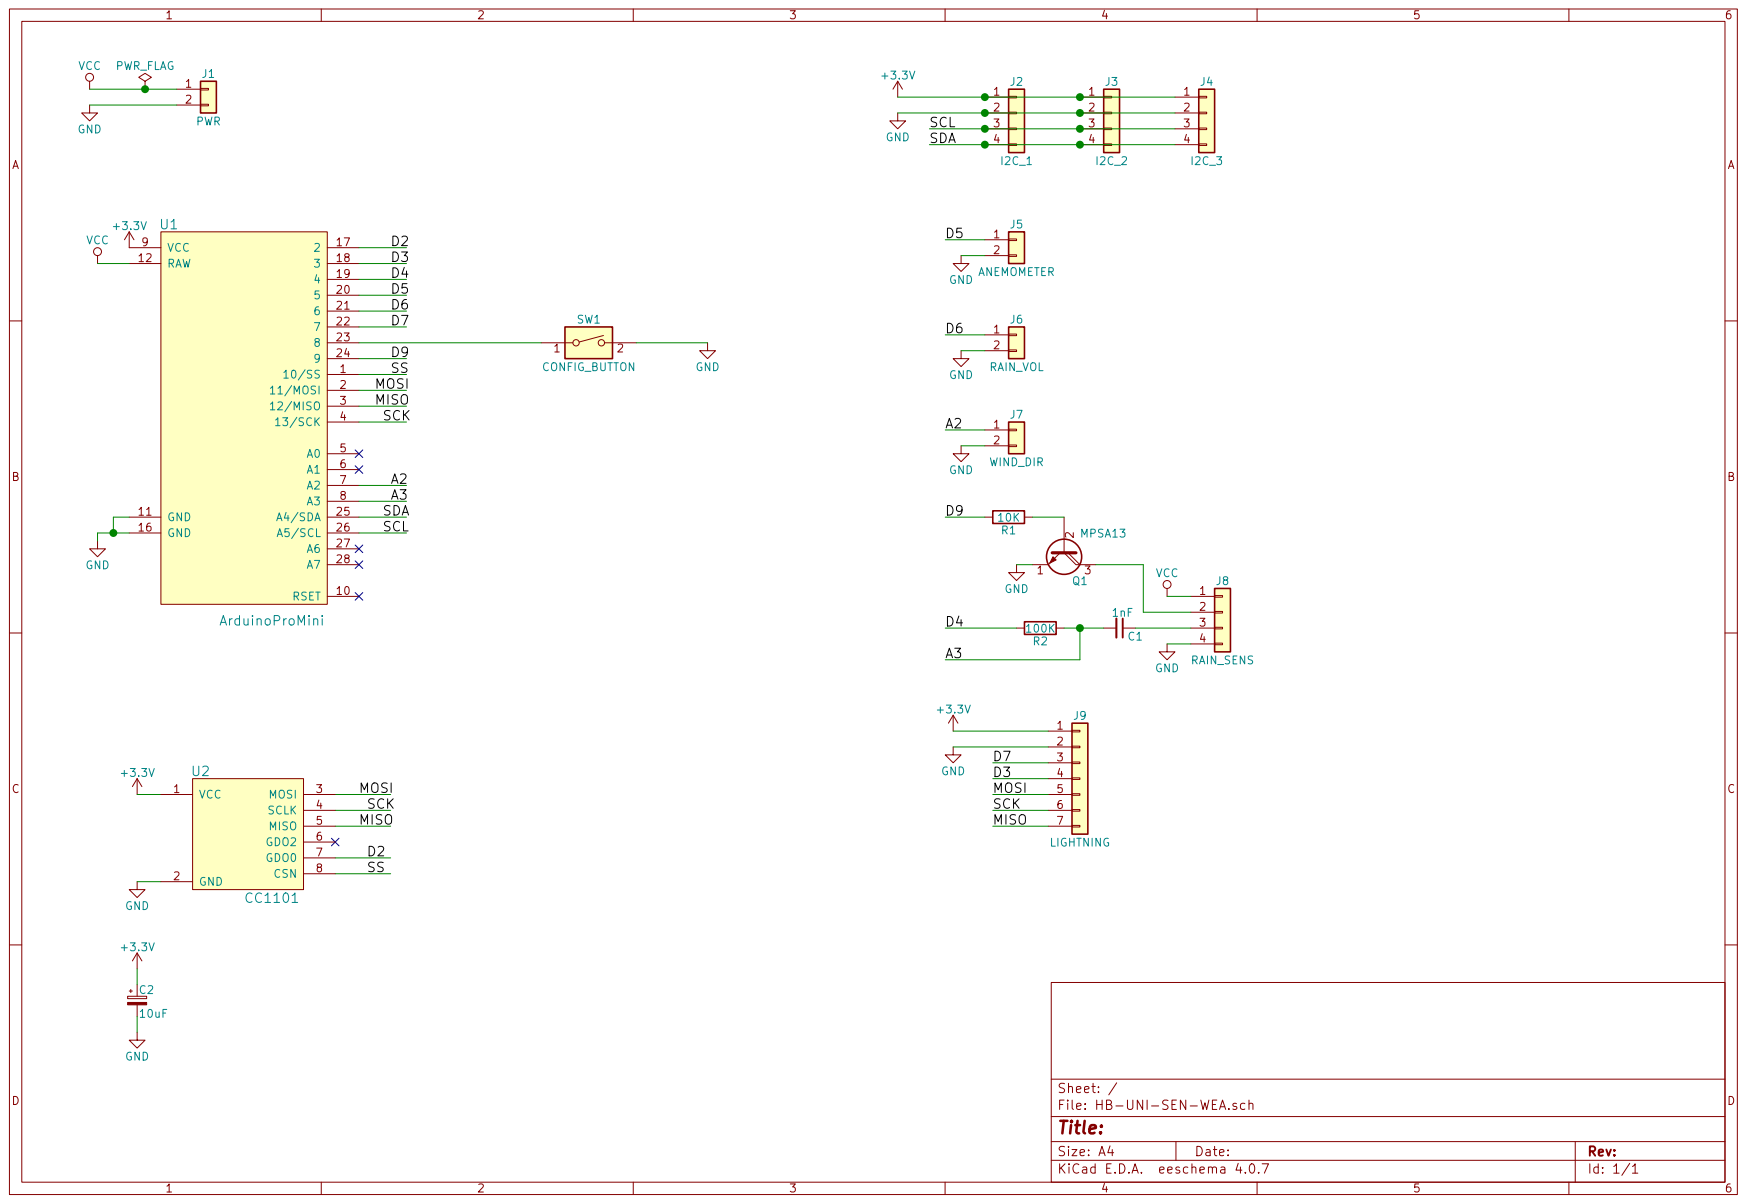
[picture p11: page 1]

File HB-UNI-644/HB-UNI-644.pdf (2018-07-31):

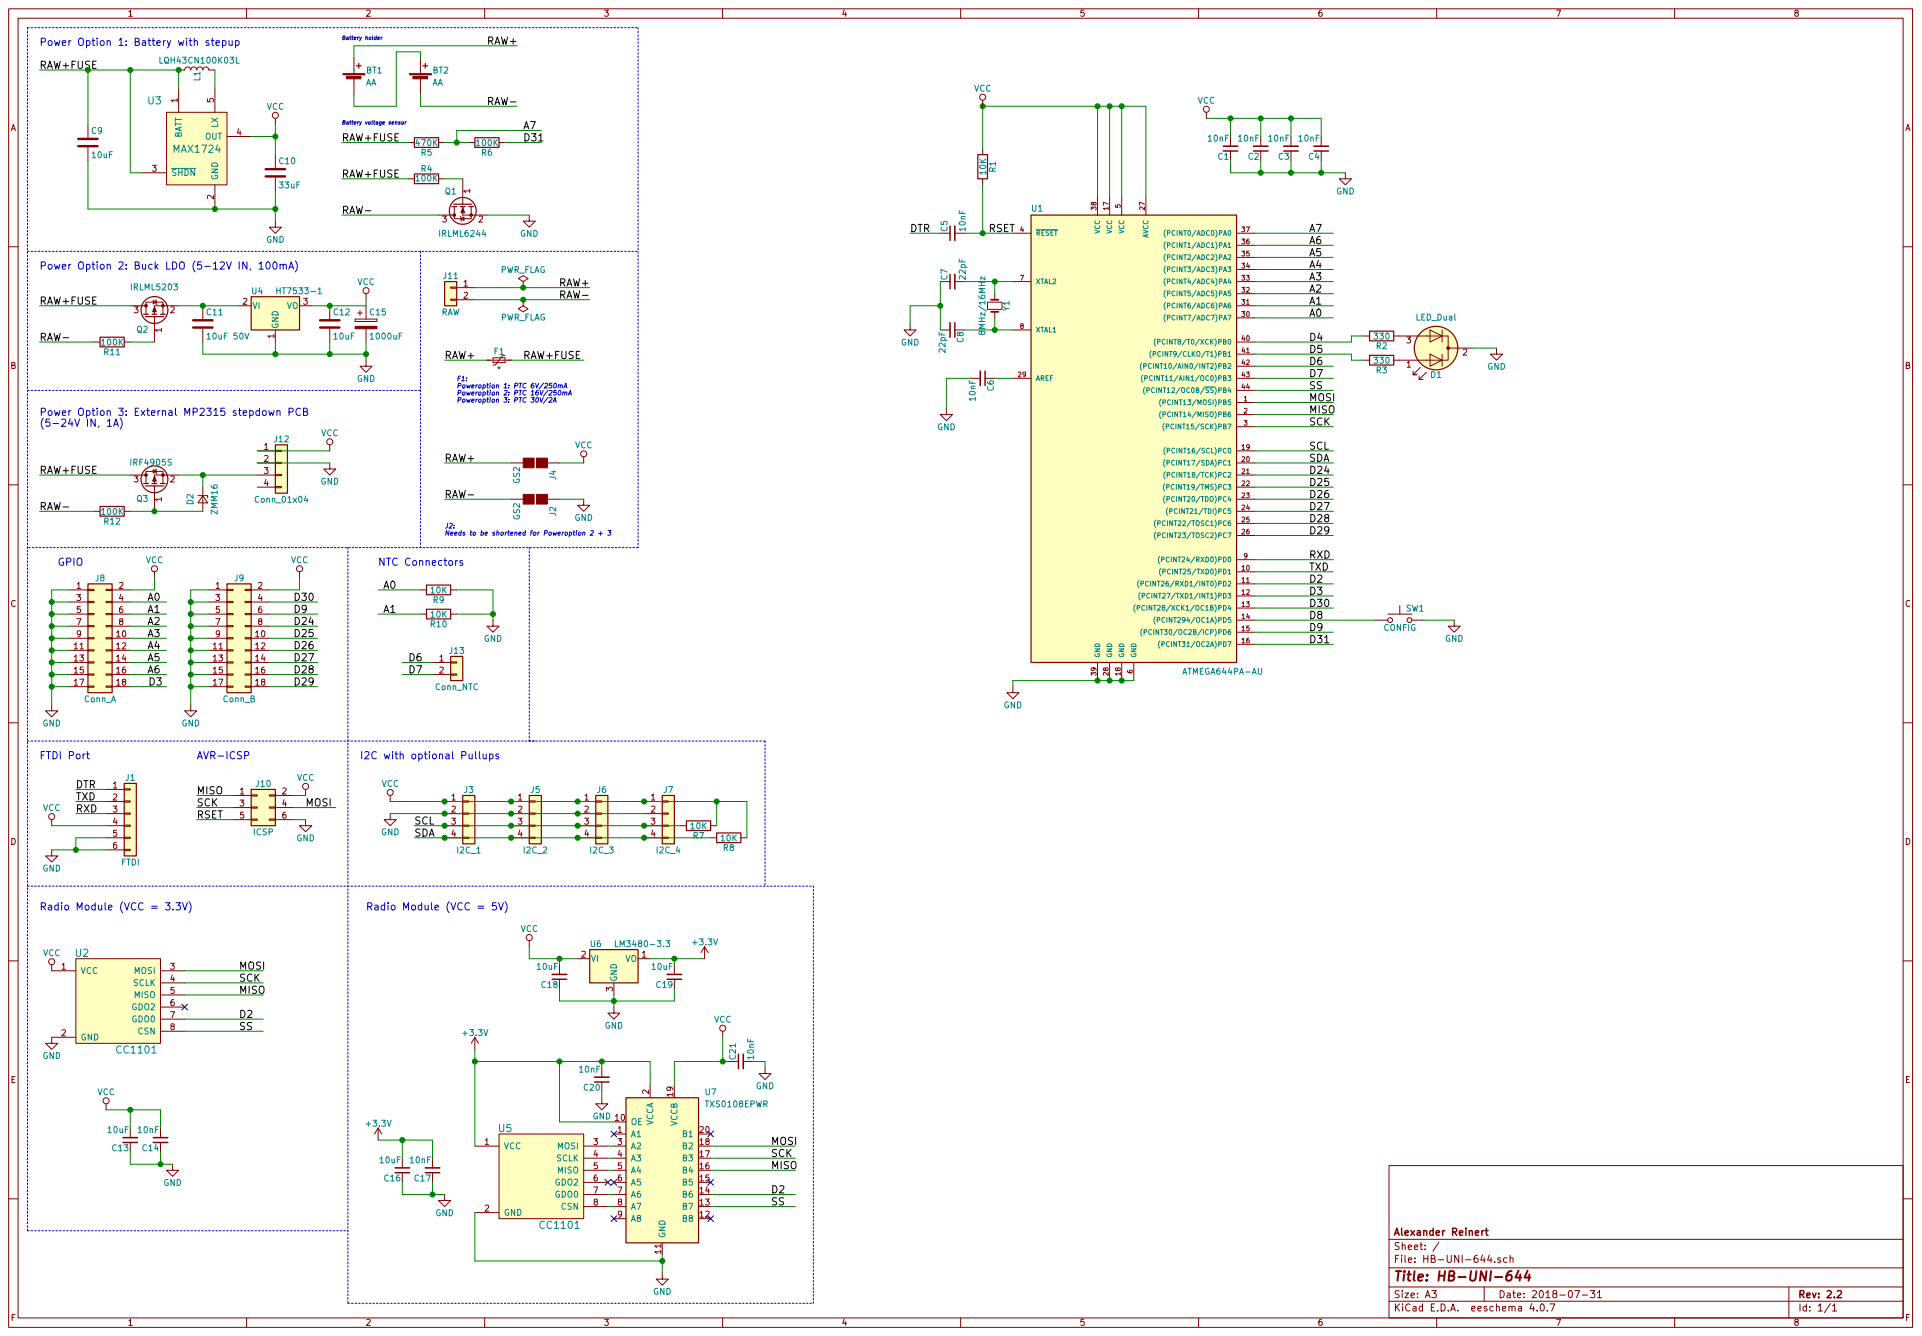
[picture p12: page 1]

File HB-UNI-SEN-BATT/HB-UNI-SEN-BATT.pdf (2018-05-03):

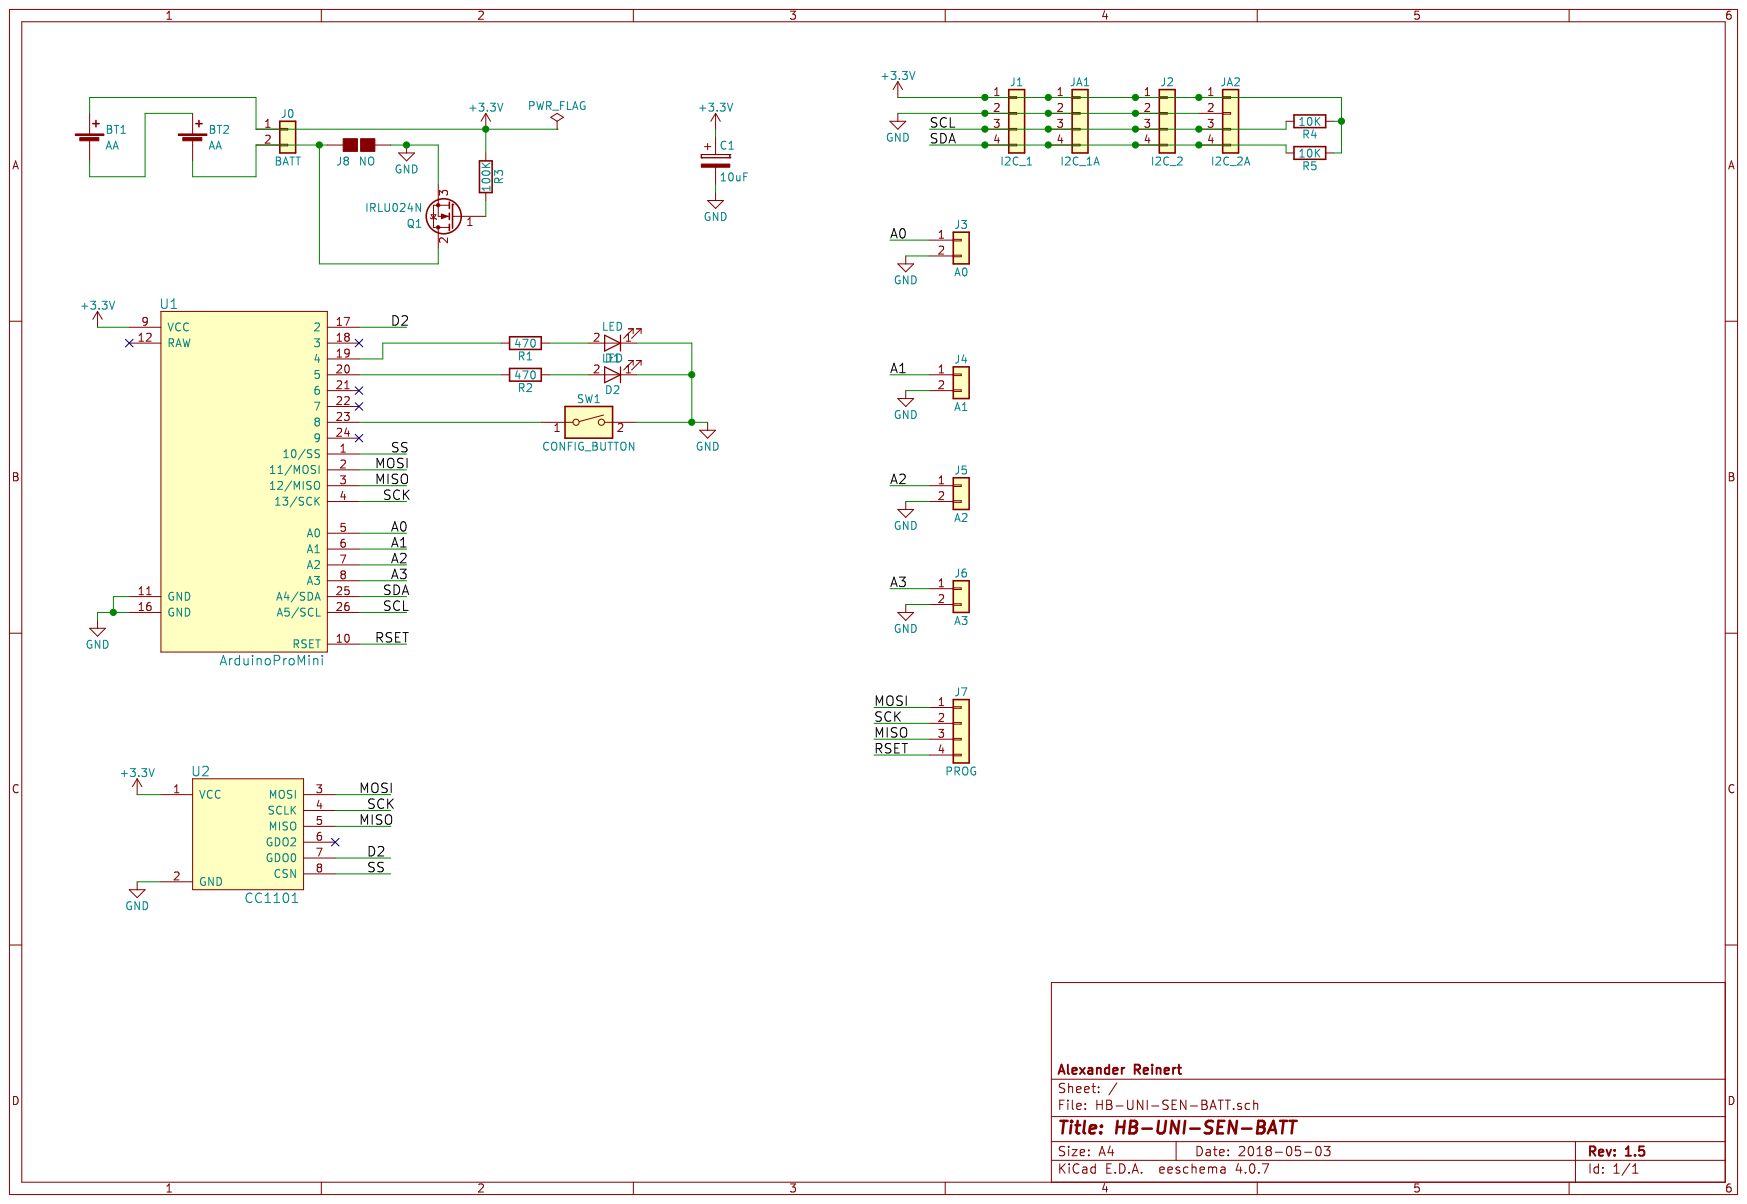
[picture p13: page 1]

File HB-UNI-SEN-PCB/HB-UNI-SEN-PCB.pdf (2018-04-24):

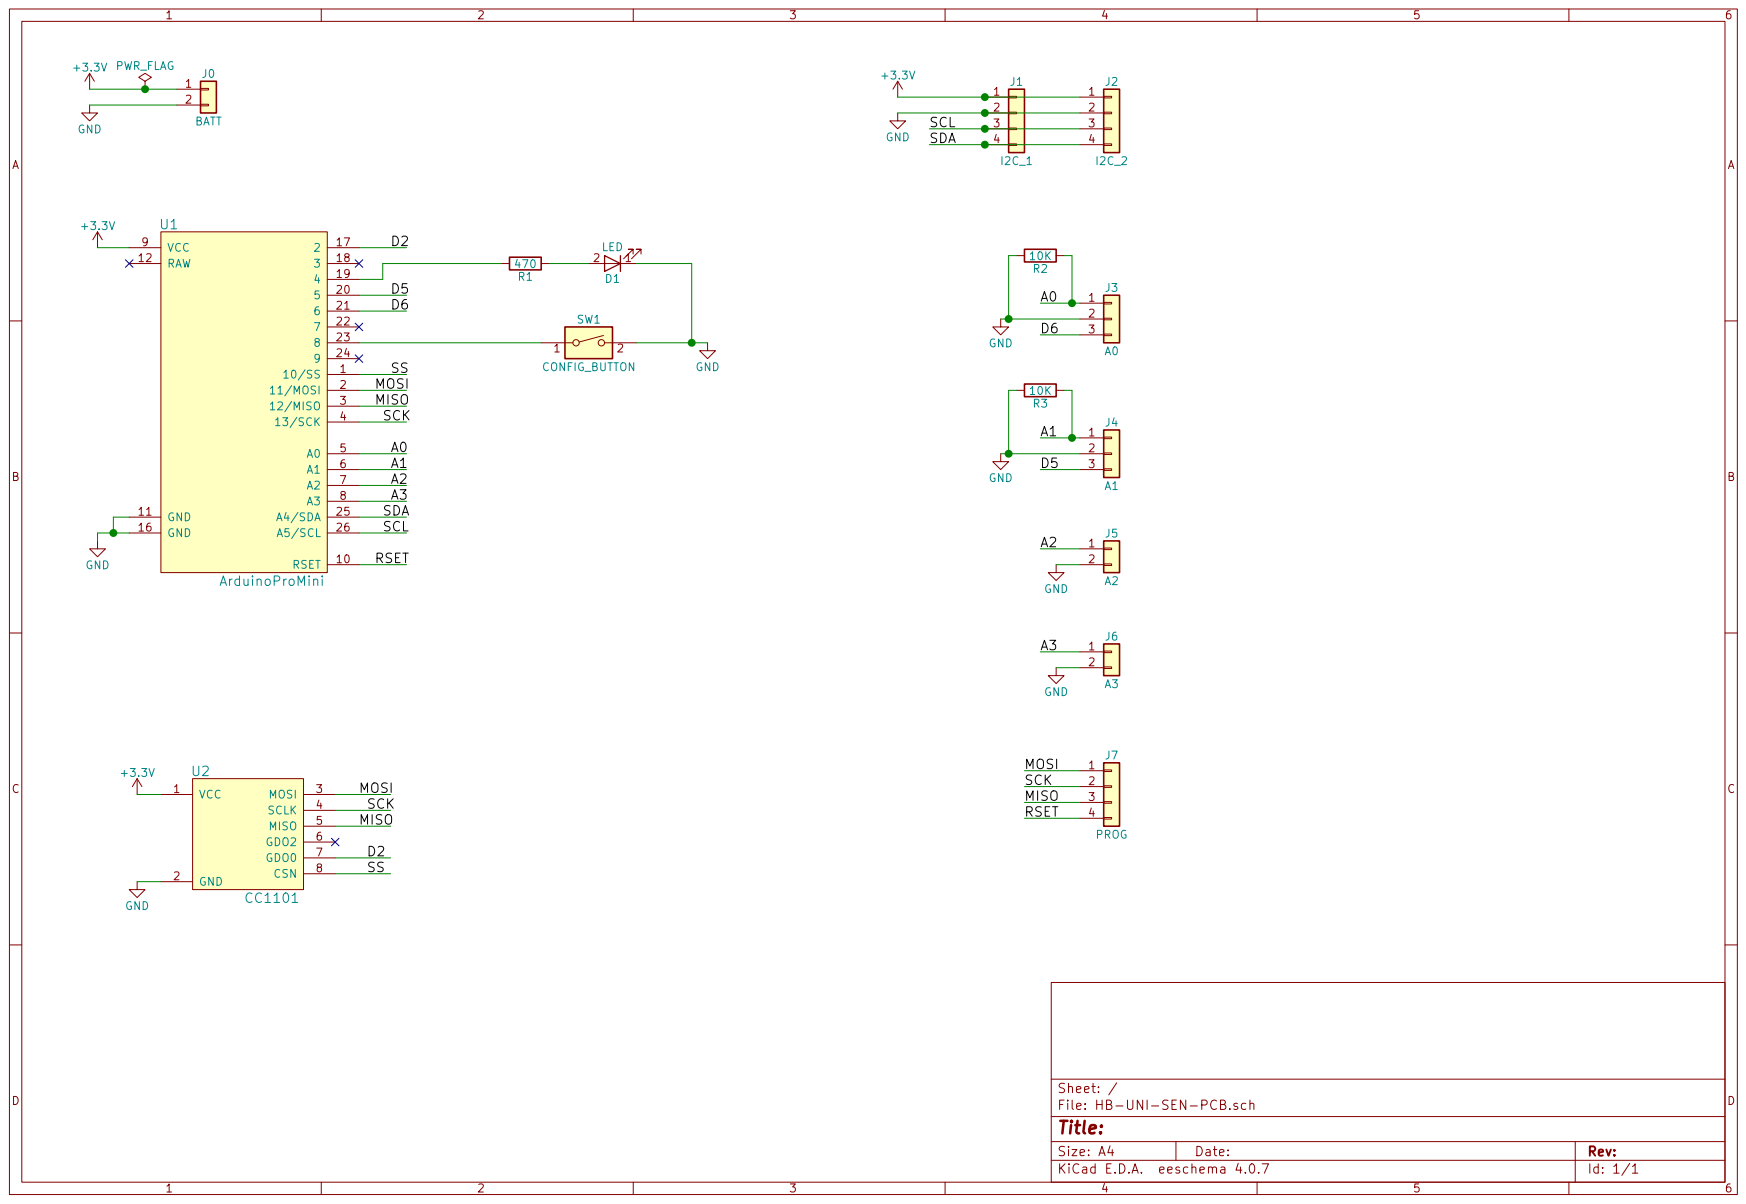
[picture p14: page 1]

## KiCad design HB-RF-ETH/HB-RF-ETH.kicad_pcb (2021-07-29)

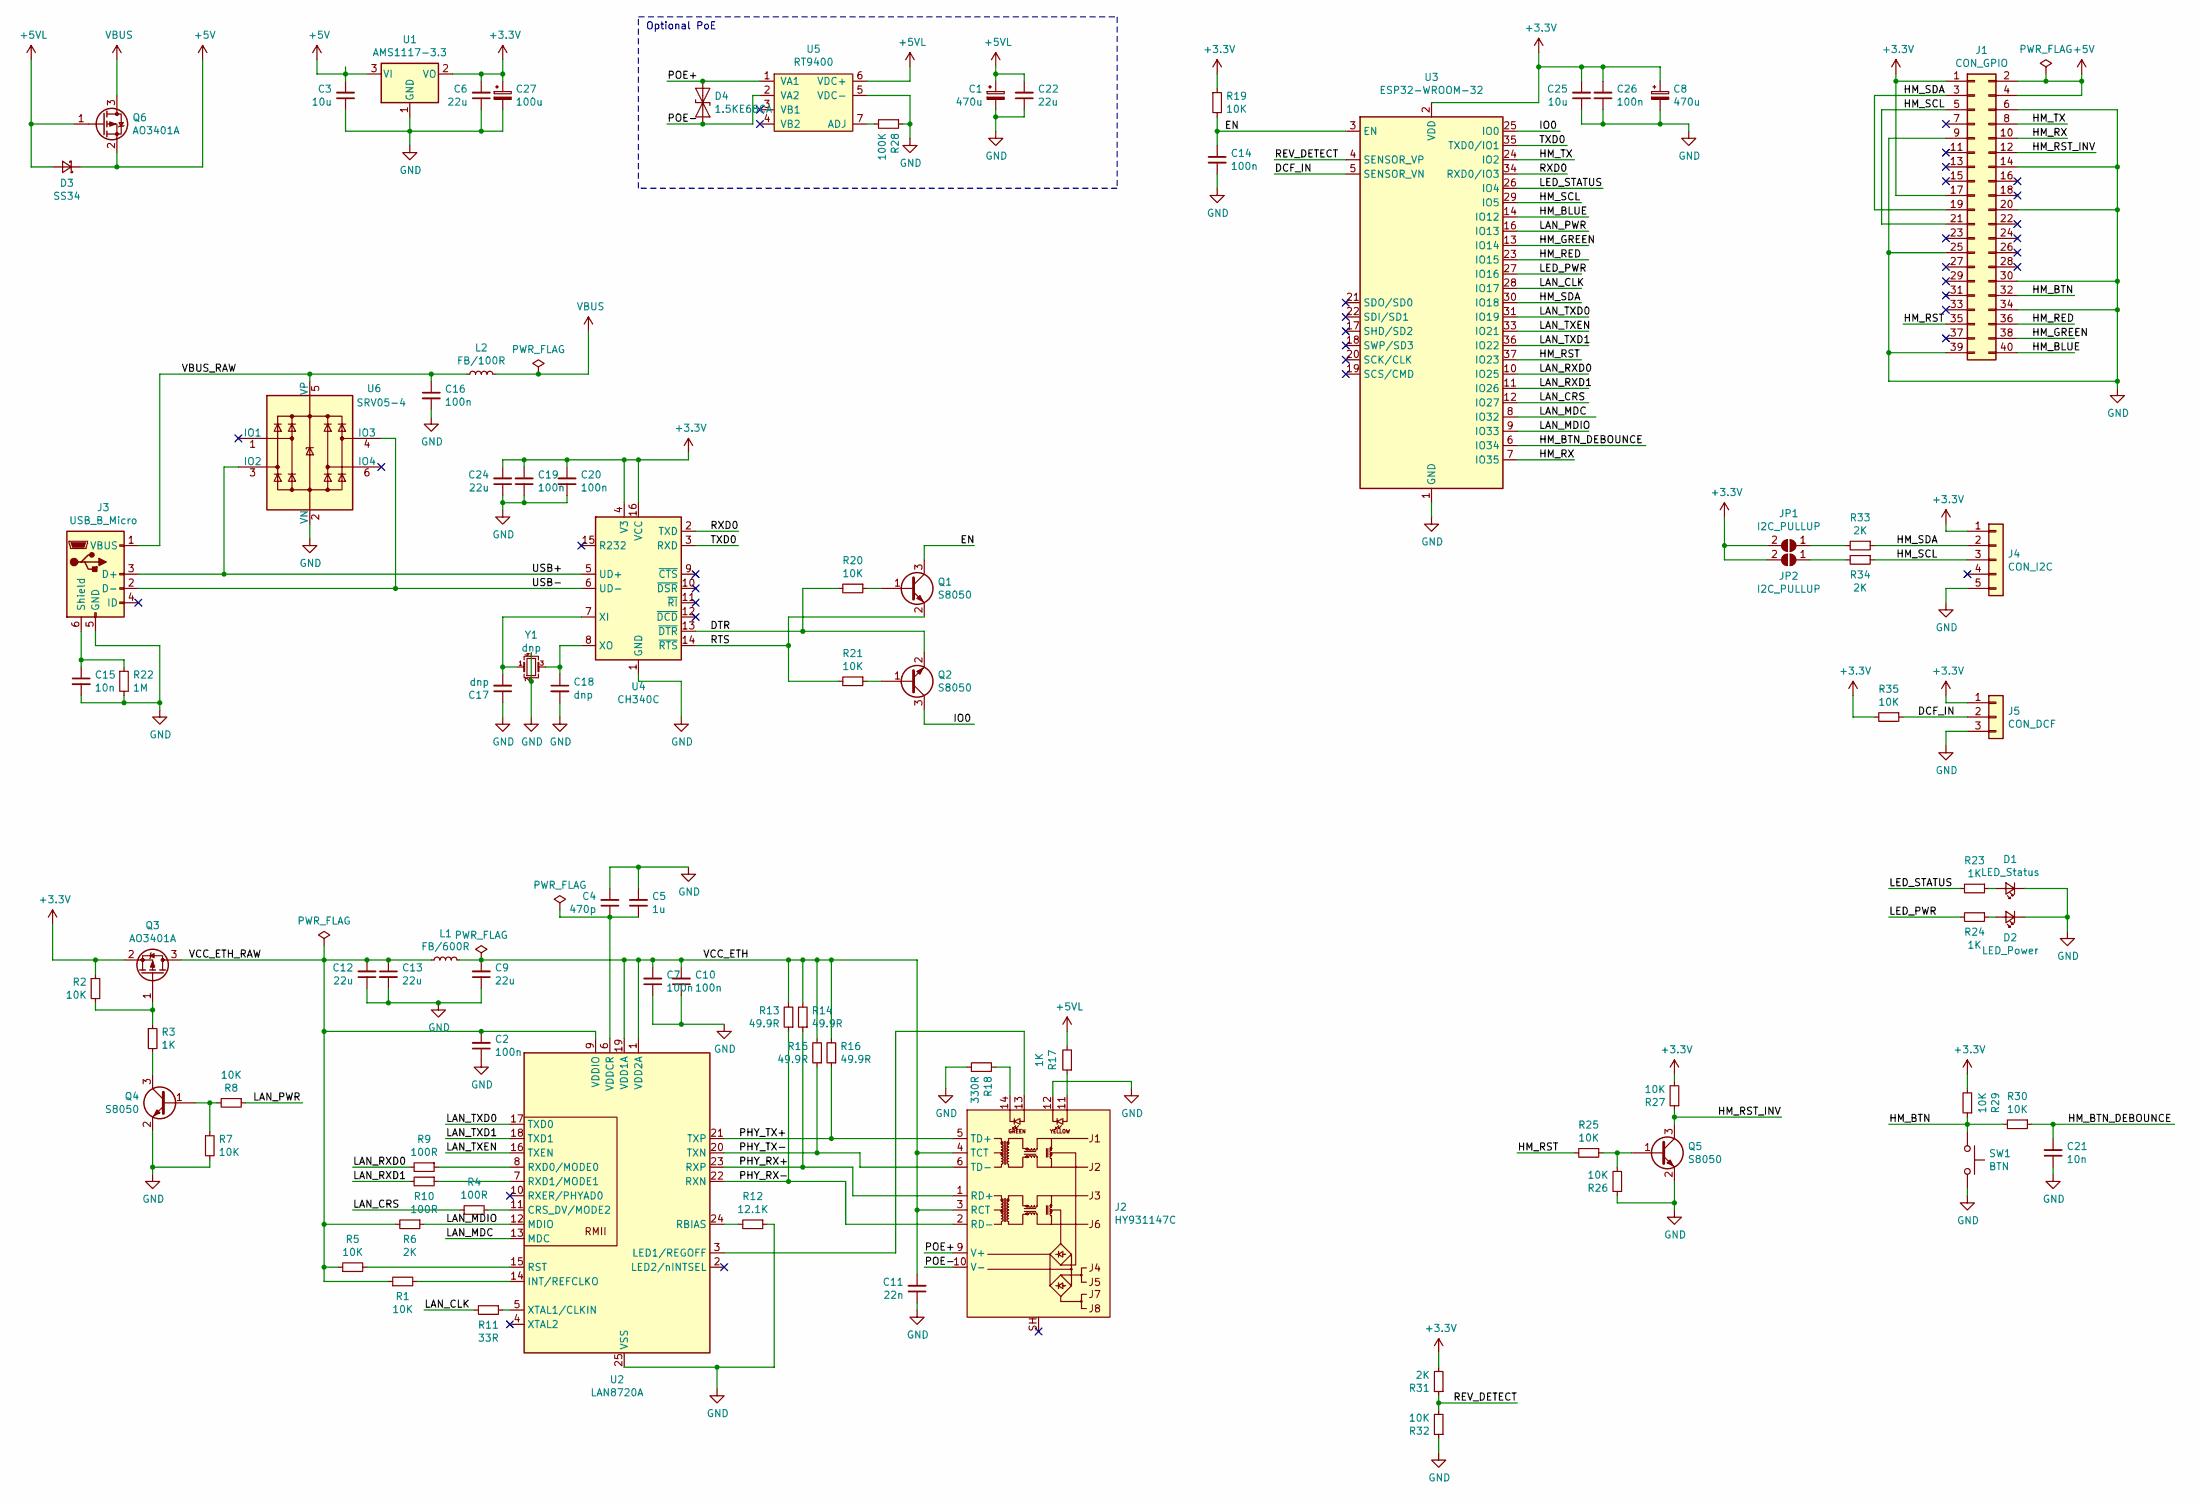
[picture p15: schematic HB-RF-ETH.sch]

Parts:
C1, C8: 470u; CP_Radial_D8.0mm_P3.50mm
C2, C7, C10, C14, C16, C19, C20, C26: 100n; C_0402_1005Metric; LCSC C1525
C3, C25: 10u; C_0603_1608Metric; LCSC C19702
C4: 470p; C_0402_1005Metric; LCSC C1537
C5: 1u; C_0603_1608Metric; LCSC C15849
C6, C9, C12, C13, C22, C24: 22u; C_0603_1608Metric; LCSC C59461
C11: 22n; C_0402_1005Metric; LCSC C1532
C15, C21: 10n; C_0402_1005Metric; LCSC C15195
C17, C18: dnp; C_0402_1005Metric
C27: 100u; CP_EIA-3528-15_AVX-H; LCSC C16133
D1: LED_Status; LED_0603_1608Metric_Castellated; LCSC C2286
D2: LED_Power; LED_0603_1608Metric_Castellated; LCSC C72043
D3: SS34; D_SMA; LCSC C8678
D4: 1.5KE68CA; D_DO-201AE_P5.08mm_Vertical_KathodeUp
J1: CON_GPIO; PinHeader_2x20_P2.54mm_Vertical
J2: HY931147C; RJ45_Hanrun_HY934711C
J3: USB_B_Micro; U-F-M5DD-Y-1
J4: CON_I2C; PinHeader_1x05_P2.54mm_Vertical
J5: CON_DCF; PinHeader_1x03_P2.54mm_Vertical
JP1, JP2: I2C_PULLUP; SolderJumper-2_P1.3mm_Open_RoundedPad1.0x1.5mm
L1: FB/600R; L_0805_2012Metric; LCSC C1017
L2: FB/100R; L_0805_2012Metric; LCSC C1015
Q1, Q2, Q4, Q5: S8050; SOT-23; LCSC C2146
Q3, Q6: AO3401A; SOT-23; LCSC C15127
R1, R2, R5, R7, R8, R19, R20, R21, R25, R26, R27, R29, R30, R32, R35: 10K; R_0402_1005Metric; LCSC C25744
R3, R17, R23, R24: 1K; R_0402_1005Metric; LCSC C11702
R4, R9, R10: 100R; R_0402_1005Metric; LCSC C25076
R6, R31, R33, R34: 2K; R_0402_1005Metric; LCSC C4109
R11: 33R; R_0402_1005Metric; LCSC C25105
R12: 12.1K; R_0402_1005Metric; LCSC C25852
R13, R14, R15, R16: 49.9R; R_0402_1005Metric; LCSC C25120
R18: 330R; R_0402_1005Metric; LCSC C25104
R22: 1M; R_0402_1005Metric; LCSC C26083
R28: 100K; R_0402_1005Metric; LCSC C25741
SW1: BTN; SW_PUSH_6mm
U1: AMS1117-3.3; SOT-223-3_TabPin2; LCSC C6186
U2: LAN8720A; QFN-24-1EP_4x4mm_P0.5mm_EP2.6x2.6mm_ThermalVias; LCSC C45223
U3: ESP32-WROOM-32; ESP32-WROOM-32_Handsoldering
U4: CH340C; SOIC-16_3.9x9.9mm_P1.27mm; LCSC C84681
U5: RT9400
U6: SRV05-4; SOT-23-6; LCSC C85364
Y1: dnp; Crystal_SMD_3225-4Pin_3.2x2.5mm

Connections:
+3V3: C6.2, C8.1, C19.2, C20.2, C24.2, C25.2, C26.2, C27.1, J1.1, J1.17, J4.1, J5.1, JP1.2 (B), JP2.2 (B), Q3.2 (S), R2.1, R19.1, R27.2, R29.2, R31.2, R35.2, U1.2 (VO), U3.2 (VDD), U4.4 (V3), U4.16 (VCC)
+5V: C3.2, D3.1 (K), J1.2, J1.4, Q6.2 (S), U1.3 (VI)
+5VL: C1.1, C22.2, D3.2 (A), Q6.1 (G), R17.2, U5.6 (VDC+)
/DCF_IN: J5.2, R35.1, U3.5 (SENSOR_VN)
/DTR: Q2.2 (E), R20.2, U4.13 (~DTR)
/EN: C14.1, Q1.3 (C), R19.2, U3.3 (EN)
/HM_BLUE: J1.40, U3.14 (IO12)
/HM_BTN: J1.32, R29.1, R30.2, SW1.1
/HM_BTN_DEBOUNCE: C21.2, R30.1, U3.6 (IO34)
/HM_GREEN: J1.38, U3.13 (IO14)
/HM_RED: J1.36, U3.23 (IO15)
/HM_RST: J1.35, R25.2, U3.37 (IO23)
/HM_RST_INV: J1.12, Q5.3 (C), R27.1
/HM_RX: J1.10, U3.7 (IO35)
/HM_SCL: J1.5, J1.21, J4.3, R34.1, U3.29 (IO5)
/HM_SDA: J1.3, J1.19, J4.2, R33.1, U3.30 (IO18)
/HM_TX: J1.8, U3.24 (IO2)
/IO0: Q2.3 (C), U3.25 (IO0)
/LAN_CLK: R11.2, U3.28 (IO17)
/LAN_CRS: R4.1, U3.12 (IO27)
/LAN_MDC: U2.13 (MDC), U3.8 (IO32)
/LAN_MDIO: R6.1, U2.12 (MDIO), U3.9 (IO33)
/LAN_PWR: R8.1, U3.16 (IO13)
/LAN_RXD0: R9.2, U3.10 (IO25)
/LAN_RXD1: R10.2, U3.11 (IO26)
/LAN_TXD0: U2.17 (TXD0), U3.31 (IO19)
/LAN_TXD1: U2.18 (TXD1), U3.36 (IO22)
/LAN_TXEN: U2.16 (TXEN), U3.33 (IO21)
/LED_PWR: R24.2, U3.27 (IO16)
/LED_STATUS: R23.2, U3.26 (IO4)
/PHY_RX+: J2.1 (RD+), R14.1, U2.23 (RXP)
/PHY_RX-: J2.2 (RD-), R13.1, U2.22 (RXN)
/PHY_TX+: J2.5 (TD+), R16.1, U2.21 (TXP)
/PHY_TX-: J2.6 (TD-), R15.1, U2.20 (TXN)
/POE+: D4.1 (A1), J2.9 (V+), U5.1 (VA1)
/POE-: D4.2 (A2), J2.10 (V-), U5.2 (VA2)
/REV_DETECT: R31.1, R32.2, U3.4 (SENSOR_VP)
/RTS: Q1.2 (E), R21.2, U4.14 (~RTS)
/RXD0: U3.34 (RXD0/IO3), U4.2 (TXD)
/TXD0: U3.35 (TXD0/IO1), U4.3 (RXD)
/USB+: J3.3 (D+), U4.5 (UD+), U6.3 (IO2)
/USB-: J3.2 (D-), U4.6 (UD-), U6.4 (IO3)
/VBUS_RAW: C16.1, J3.1 (VBUS), L2.1, U6.5 (VP)
/VCC_ETH: C7.2, C9.2, C10.2, C11.2, J2.3 (RCT), J2.4 (TCT), L1.2, R13.2, R14.2, R15.2, R16.2, U2.1 (VDD2A), U2.19 (VDD1A)
/VCC_ETH_RAW: C2.2, C12.2, C13.1, L1.1, Q3.3 (D), R1.1, R5.1, R6.2, U2.9 (VDDIO)
GND: C1.2, C2.1, C3.1, C4.2, C5.2, C6.1, C7.1, C8.2, C9.1, C10.1, C11.1, C12.1, C13.2, C14.2, C15.2, C16.2, C17.1, C18.2, C19.1, C20.1, C21.1, C22.1, C24.1, C25.1, C26.1, C27.2, D1.1 (K), D2.1 (K), J1.6, J1.9, J1.14, J1.20, J1.25, J1.30, J1.34, J1.39, J2.12, J3.5 (GND), J4.5, J5.3, Q4.2 (E), Q5.2 (E), R7.2, R12.1, R18.1, R22.2, R26.1, R28.1, R32.1, SW1.2, U1.1 (GND), U2.25 (VSS), U3.1 (GND), U3.15 (GND), U3.38 (GND), U3.39 (GND), U4.1 (GND), U5.5 (VDC-), U6.2 (VN), Y1.2, Y1.4
unnamed: C4.1, C5.1, U2.6 (VDDCR)
unnamed: C15.1, J3.6 (Shield), R22.1
unnamed: C17.2, U4.7 (XI), Y1.1
unnamed: C18.1, U4.8 (XO), Y1.3
unnamed: D1.2 (A), R23.1
unnamed: D2.2 (A), R24.1
unnamed: J2.11, R17.1
unnamed: J2.13, U2.3 (LED1/REGOFF)
unnamed: J2.14, R18.2
unnamed: JP1.1 (A), R33.2
unnamed: JP2.1 (A), R34.2
unnamed: Q1.1 (B), R20.1
unnamed: Q2.1 (B), R21.1
unnamed: Q3.1 (G), R2.2, R3.1
unnamed: Q4.1 (B), R7.1, R8.2
unnamed: Q4.3 (C), R3.2
unnamed: Q5.1 (B), R25.1, R26.2
unnamed: R1.2, U2.14 (INT/REFCLKO)
unnamed: R4.2, U2.11 (CRS_DV/MODE2)
unnamed: R5.2, U2.15 (RST)
unnamed: R9.1, U2.8 (RXD0/MODE0)
unnamed: R10.1, U2.7 (RXD1/MODE1)
unnamed: R11.1, U2.5 (XTAL1/CLKIN)
unnamed: R12.2, U2.24 (RBIAS)
unnamed: R28.2, U5.7 (ADJ)
VBUS: L2.2, Q6.3 (D)

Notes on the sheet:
Optional PoE

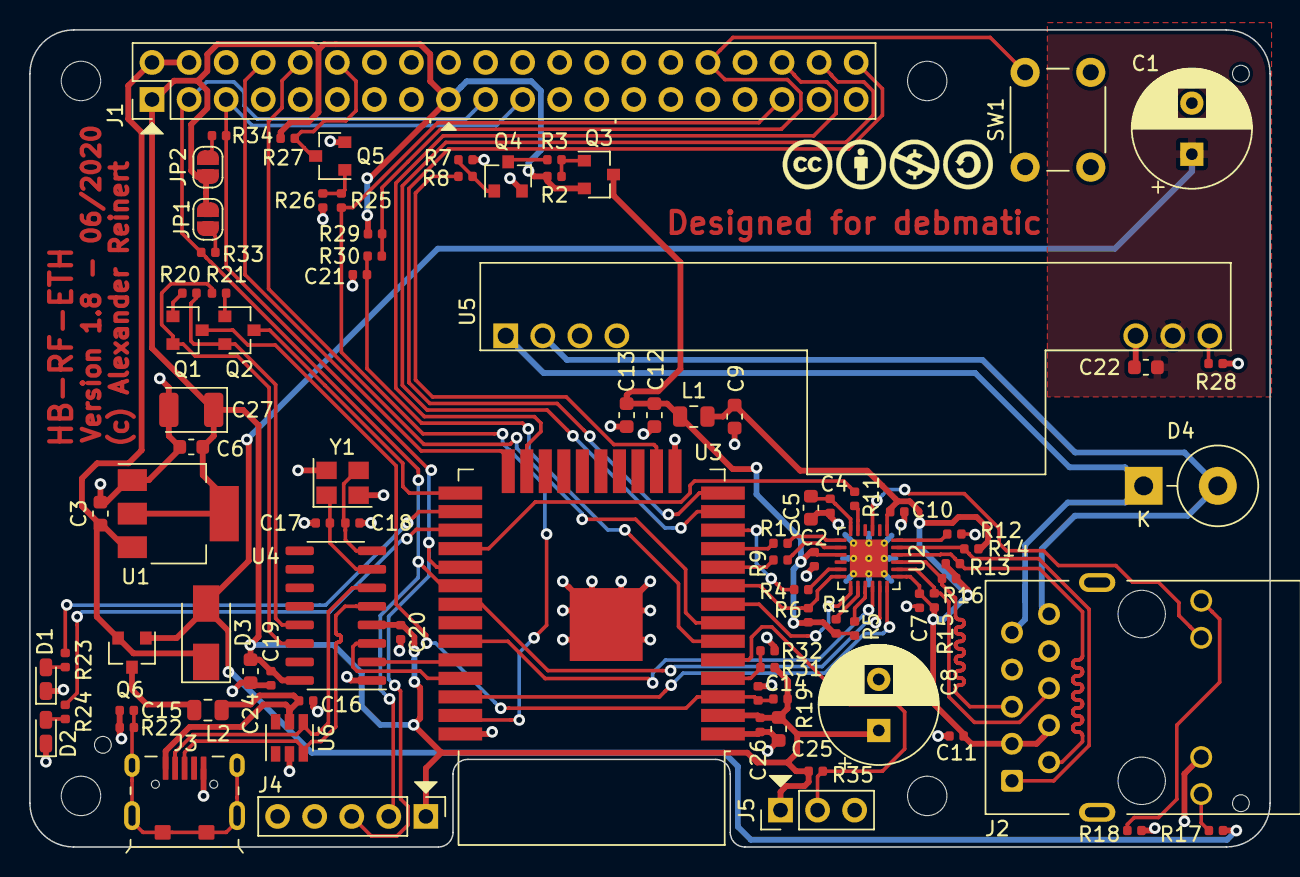
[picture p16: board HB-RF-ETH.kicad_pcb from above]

Board: 2 copper layers, 85.0 x 56.0 mm, 88 parts (0 on the bottom side), 72 nets.

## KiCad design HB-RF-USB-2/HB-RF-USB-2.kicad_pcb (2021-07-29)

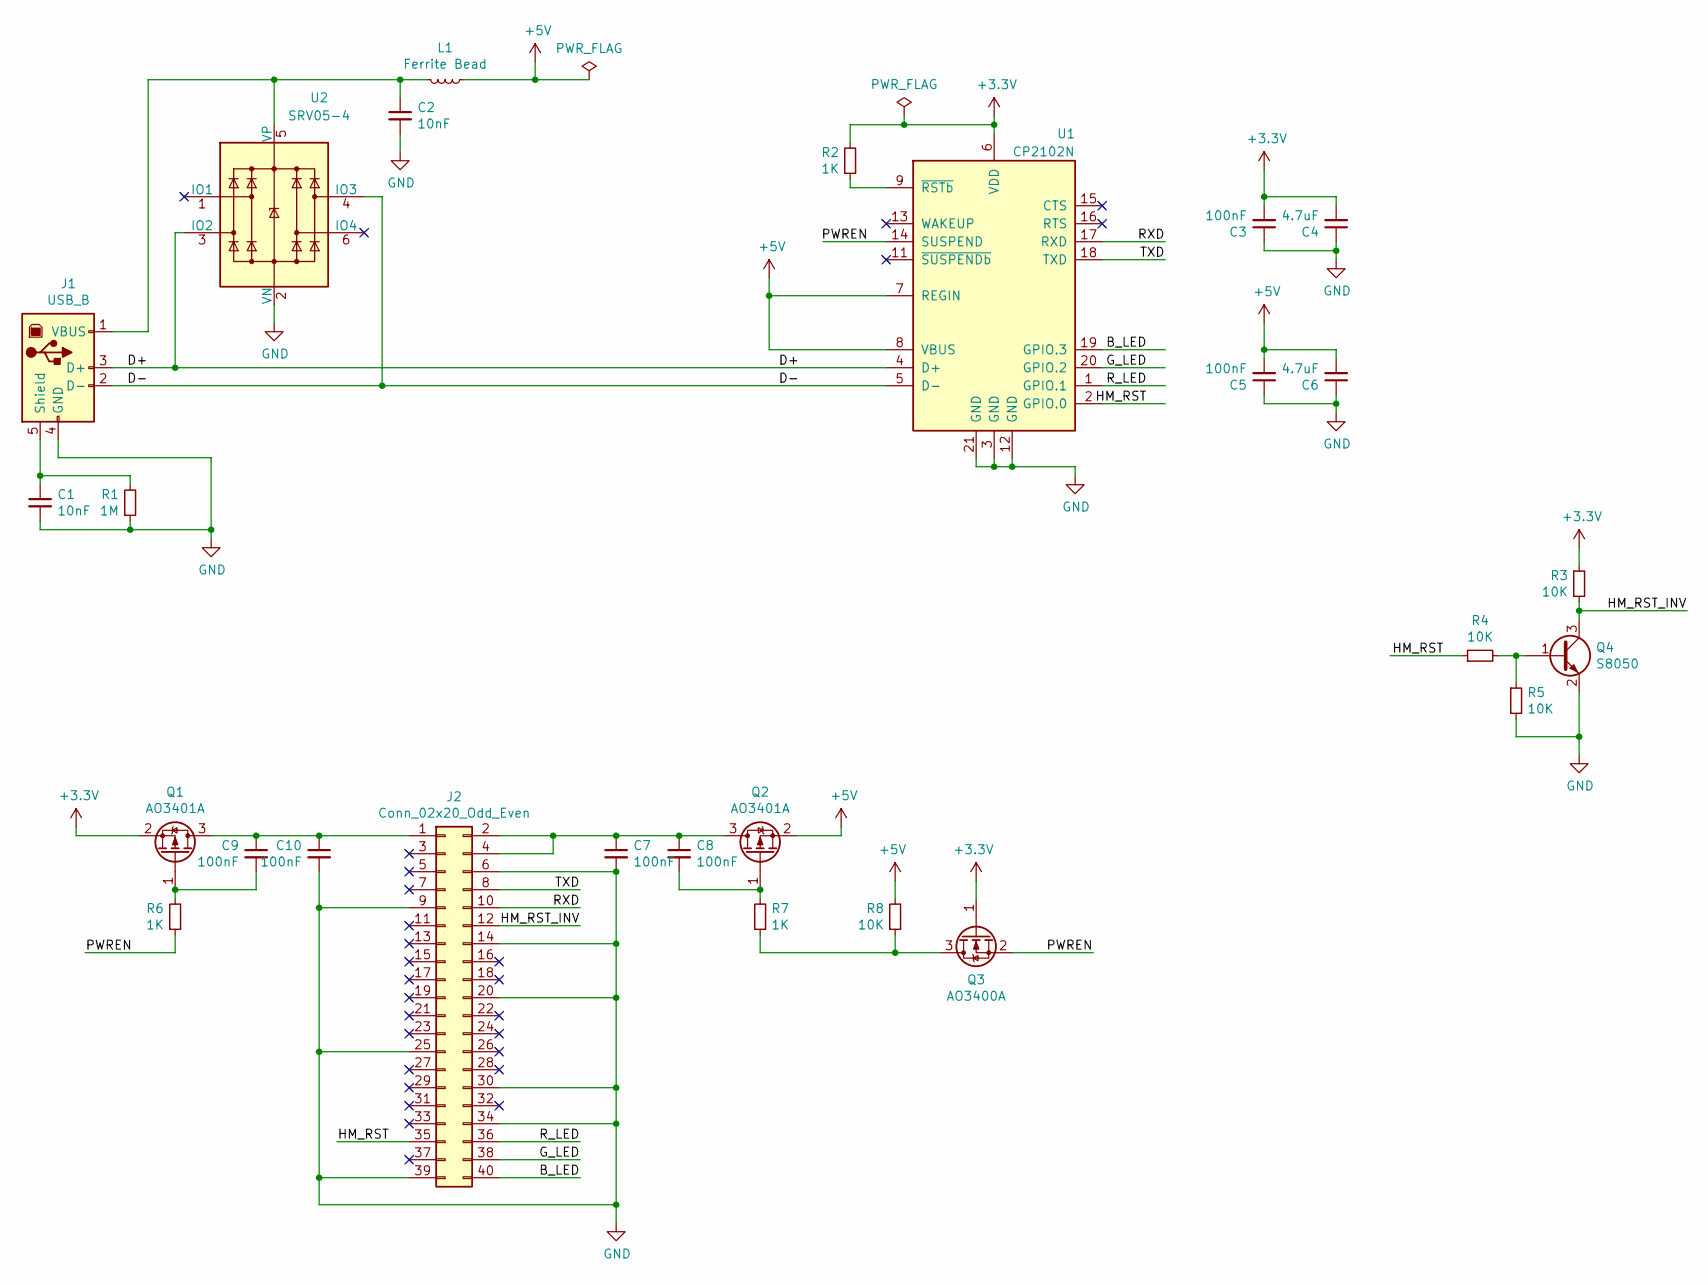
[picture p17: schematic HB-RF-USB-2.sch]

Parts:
C1, C2: 10nF; C_0402_1005Metric; LCSC C15195
C3, C5, C7, C8, C9, C10: 100nF; C_0402_1005Metric; LCSC C1525
C4, C6: 4.7uF; C_0603_1608Metric; LCSC C19666
J1: USB_B; USB_B_OST_USB-B1HSxx_Horizontal
J2: Conn_02x20_Odd_Even; PinHeader_2x20_P2.54mm_Vertical
L1: Ferrite Bead; L_0805_2012Metric; LCSC C1015
Q1, Q2: AO3401A; SOT-23; LCSC C15127
Q3: AO3400A; SOT-23; LCSC C20917
Q4: S8050; SOT-23; LCSC C2146
R1: 1M; R_0402_1005Metric; LCSC C26083
R2, R6, R7: 1K; R_0402_1005Metric; LCSC C11702
R3, R4, R5, R8: 10K; R_0402_1005Metric; LCSC C25744
U1: CP2102N; SiliconLabs_QFN-20-1EP_3x3mm_P0.5mm; LCSC C89049
U2: SRV05-4; SOT-23-6; LCSC C85364

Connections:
+3V3: C3.2, C4.2, Q1.2 (S), Q3.1 (G), R2.2, R3.1, U1.6 (VDD)
+5V: C5.2, C6.2, L1.1, Q2.2 (S), R8.2, U1.7 (REGIN), U1.8 (VBUS)
/B_LED: J2.40, U1.19 (GPIO.3)
/D+: J1.3 (D+), U1.4 (D+), U2.3 (IO2)
/D-: J1.2 (D-), U1.5 (D-), U2.4 (IO3)
/G_LED: J2.38, U1.20 (GPIO.2)
/HM_RST: J2.35, R4.1, U1.2 (GPIO.0)
/HM_RST_INV: J2.12, Q4.3 (C), R3.2
/PWREN: Q3.2 (S), R6.1, U1.14 (SUSPEND)
/RXD: J2.10, U1.17 (RXD)
/R_LED: J2.36, U1.1 (GPIO.1)
/TXD: J2.8, U1.18 (TXD)
GND: C1.2, C2.2, C3.1, C4.1, C5.1, C6.1, C7.2, C10.2, J1.4 (GND), J2.6, J2.9, J2.14, J2.20, J2.25, J2.30, J2.34, J2.39, Q4.2 (E), R1.1, R5.2, U1.3 (GND), U1.12 (GND), U1.21 (GND), U2.2 (VN)
unnamed: C1.1, J1.5 (Shield), R1.2
unnamed: C2.1, J1.1 (VBUS), L1.2, U2.5 (VP)
unnamed: C7.1, C8.1, J2.2, J2.4, Q2.3 (D)
unnamed: C8.2, Q2.1 (G), R7.2
unnamed: C9.2, Q1.1 (G), R6.2
unnamed: C9.1, C10.1, J2.1, Q1.3 (D)
unnamed: Q3.3 (D), R7.1, R8.1
unnamed: Q4.1 (B), R4.2, R5.1
unnamed: R2.1, U1.9 (~RSTb)

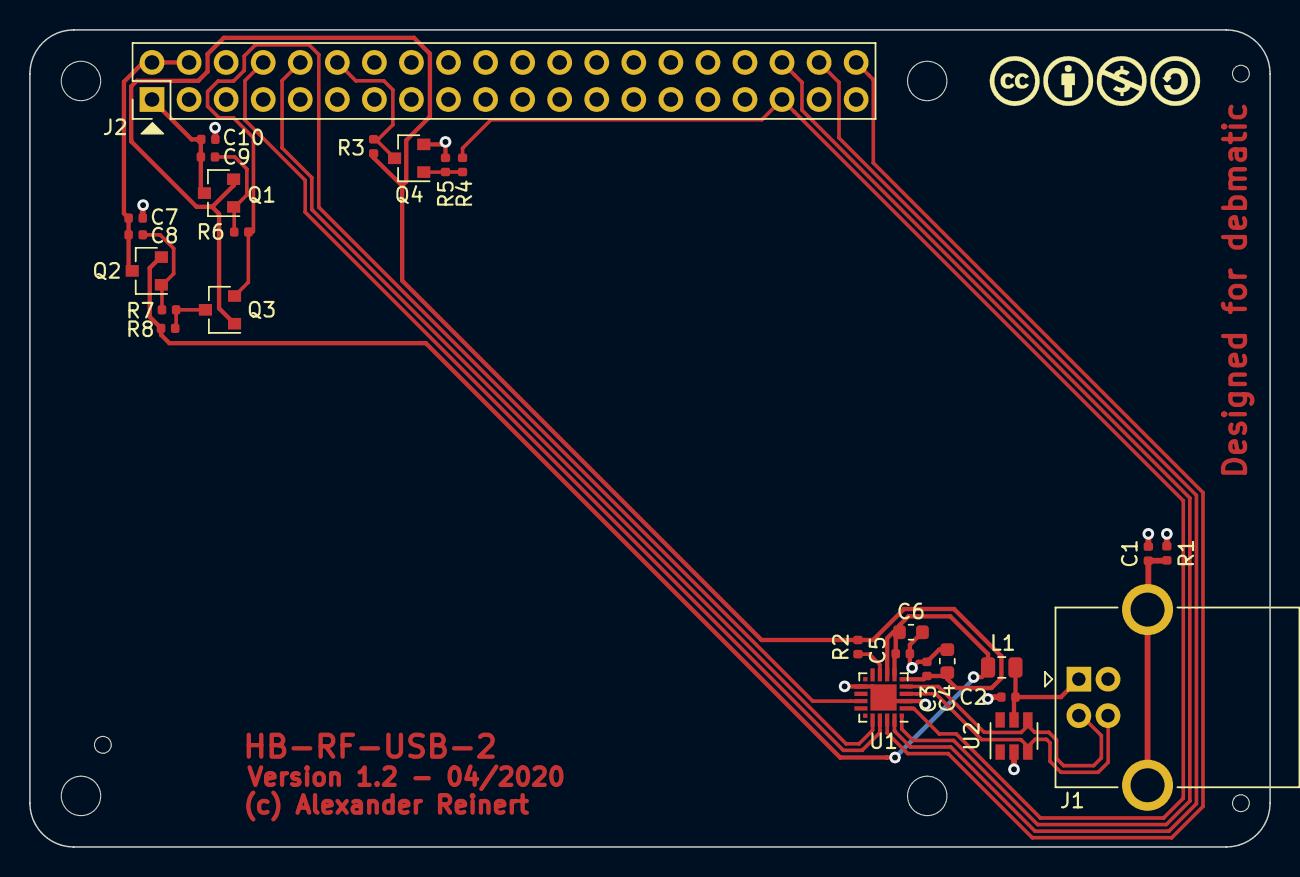
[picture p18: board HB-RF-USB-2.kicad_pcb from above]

Board: 2 copper layers, 85.0 x 56.0 mm, 27 parts (0 on the bottom side), 22 nets.

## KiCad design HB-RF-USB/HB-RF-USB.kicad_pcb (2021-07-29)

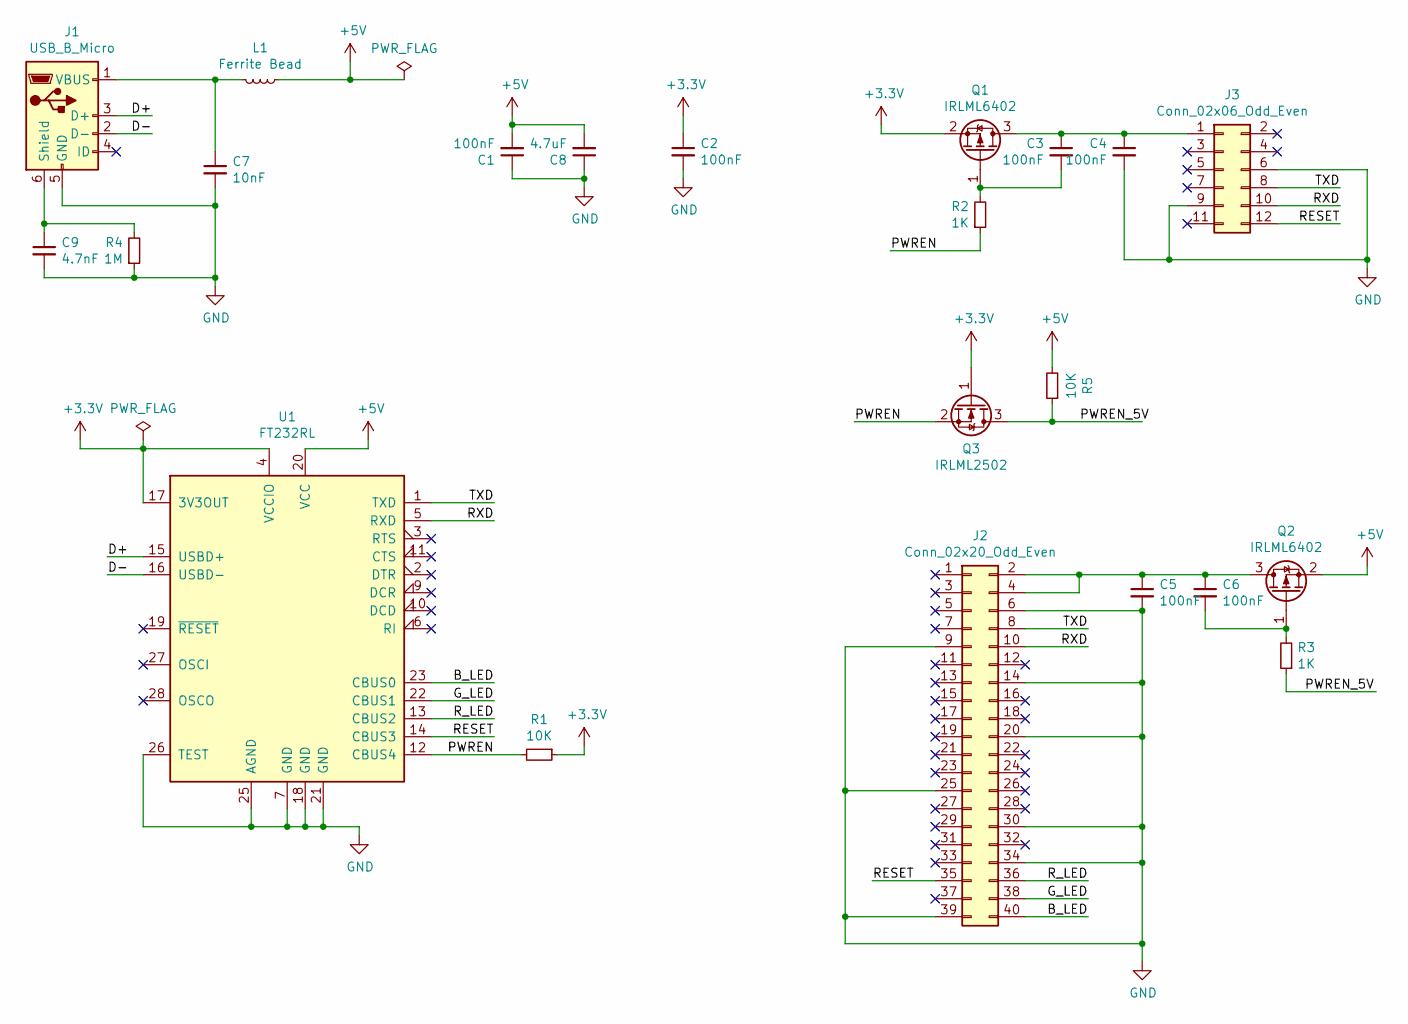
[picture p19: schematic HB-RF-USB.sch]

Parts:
C1, C2, C3, C4, C5, C6: 100nF; C_0805_2012Metric_Pad1.15x1.40mm_HandSolder
C7: 10nF; C_0805_2012Metric_Pad1.15x1.40mm_HandSolder
C8: 4.7uF; C_0805_2012Metric_Pad1.15x1.40mm_HandSolder
C9: 4.7nF; C_0805_2012Metric_Pad1.15x1.40mm_HandSolder
J1: USB_B_Micro; U-F-M5DD-Y-1
J2: Conn_02x20_Odd_Even; PinHeader_2x20_P2.54mm_Vertical
J3: Conn_02x06_Odd_Even; PinHeader_2x06_P2.54mm_Vertical
L1: Ferrite Bead; L_0805_2012Metric_Pad1.15x1.40mm_HandSolder
Q1, Q2: IRLML6402; SOT-23_Handsoldering
Q3: IRLML2502; SOT-23_Handsoldering
R1, R5: 10K; R_0805_2012Metric_Pad1.15x1.40mm_HandSolder
R2, R3: 1K; R_0805_2012Metric_Pad1.15x1.40mm_HandSolder
R4: 1M; R_0805_2012Metric_Pad1.15x1.40mm_HandSolder
U1: FT232RL; SSOP-28_5.3x10.2mm_P0.65mm

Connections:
+3V3: C2.1, Q1.2 (S), Q3.1 (G), R1.1, U1.4 (VCCIO), U1.17 (3V3OUT)
+5V: C1.2, C8.2, L1.1, Q2.2 (S), R5.2, U1.20 (VCC)
/B_LED: J2.40, U1.23 (CBUS0)
/D+: J1.3 (D+), U1.15 (USBD+)
/D-: J1.2 (D-), U1.16 (USBD-)
/G_LED: J2.38, U1.22 (CBUS1)
/PWREN: Q3.2 (S), R1.2, R2.1, U1.12 (CBUS4)
/PWREN_5V: Q3.3 (D), R3.1, R5.1
/RESET: J2.35, J3.12, U1.14 (CBUS3)
/RXD: J2.10, J3.10, U1.5 (RXD)
/R_LED: J2.36, U1.13 (CBUS2)
/TXD: J2.8, J3.8, U1.1 (TXD)
GND: C1.1, C2.2, C4.2, C5.2, C7.2, C8.1, C9.2, J1.5 (GND), J2.6, J2.9, J2.14, J2.20, J2.25, J2.30, J2.34, J2.39, J3.6, J3.9, R4.1, U1.7 (GND), U1.18 (GND), U1.21 (GND), U1.25 (AGND), U1.26 (TEST)
unnamed: C3.1, C4.1, J3.1, Q1.3 (D)
unnamed: C3.2, Q1.1 (G), R2.2
unnamed: C5.1, C6.1, J2.2, J2.4, Q2.3 (D)
unnamed: C6.2, Q2.1 (G), R3.2
unnamed: C7.1, J1.1 (VBUS), L1.2
unnamed: C9.1, J1.6 (Shield), R4.2

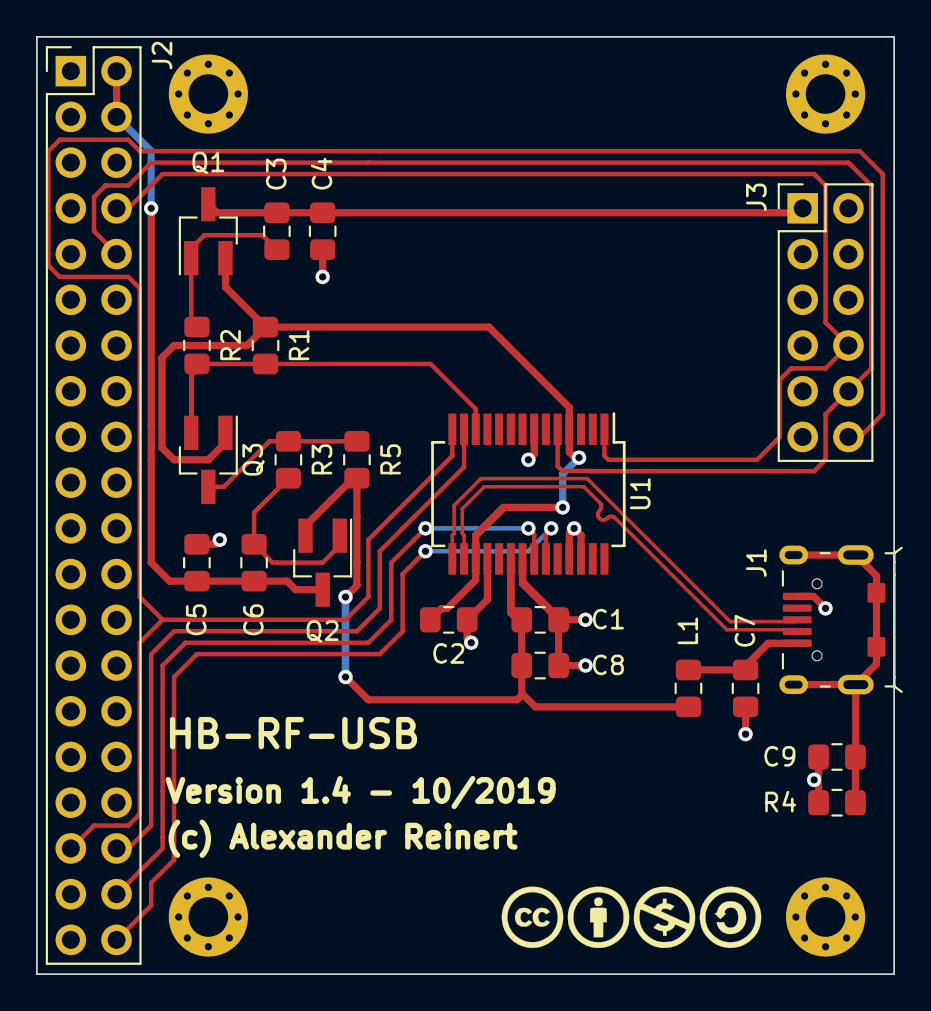
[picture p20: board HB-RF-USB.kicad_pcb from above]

Board: 2 copper layers, 47.6 x 52.1 mm, 22 parts (0 on the bottom side), 19 nets.

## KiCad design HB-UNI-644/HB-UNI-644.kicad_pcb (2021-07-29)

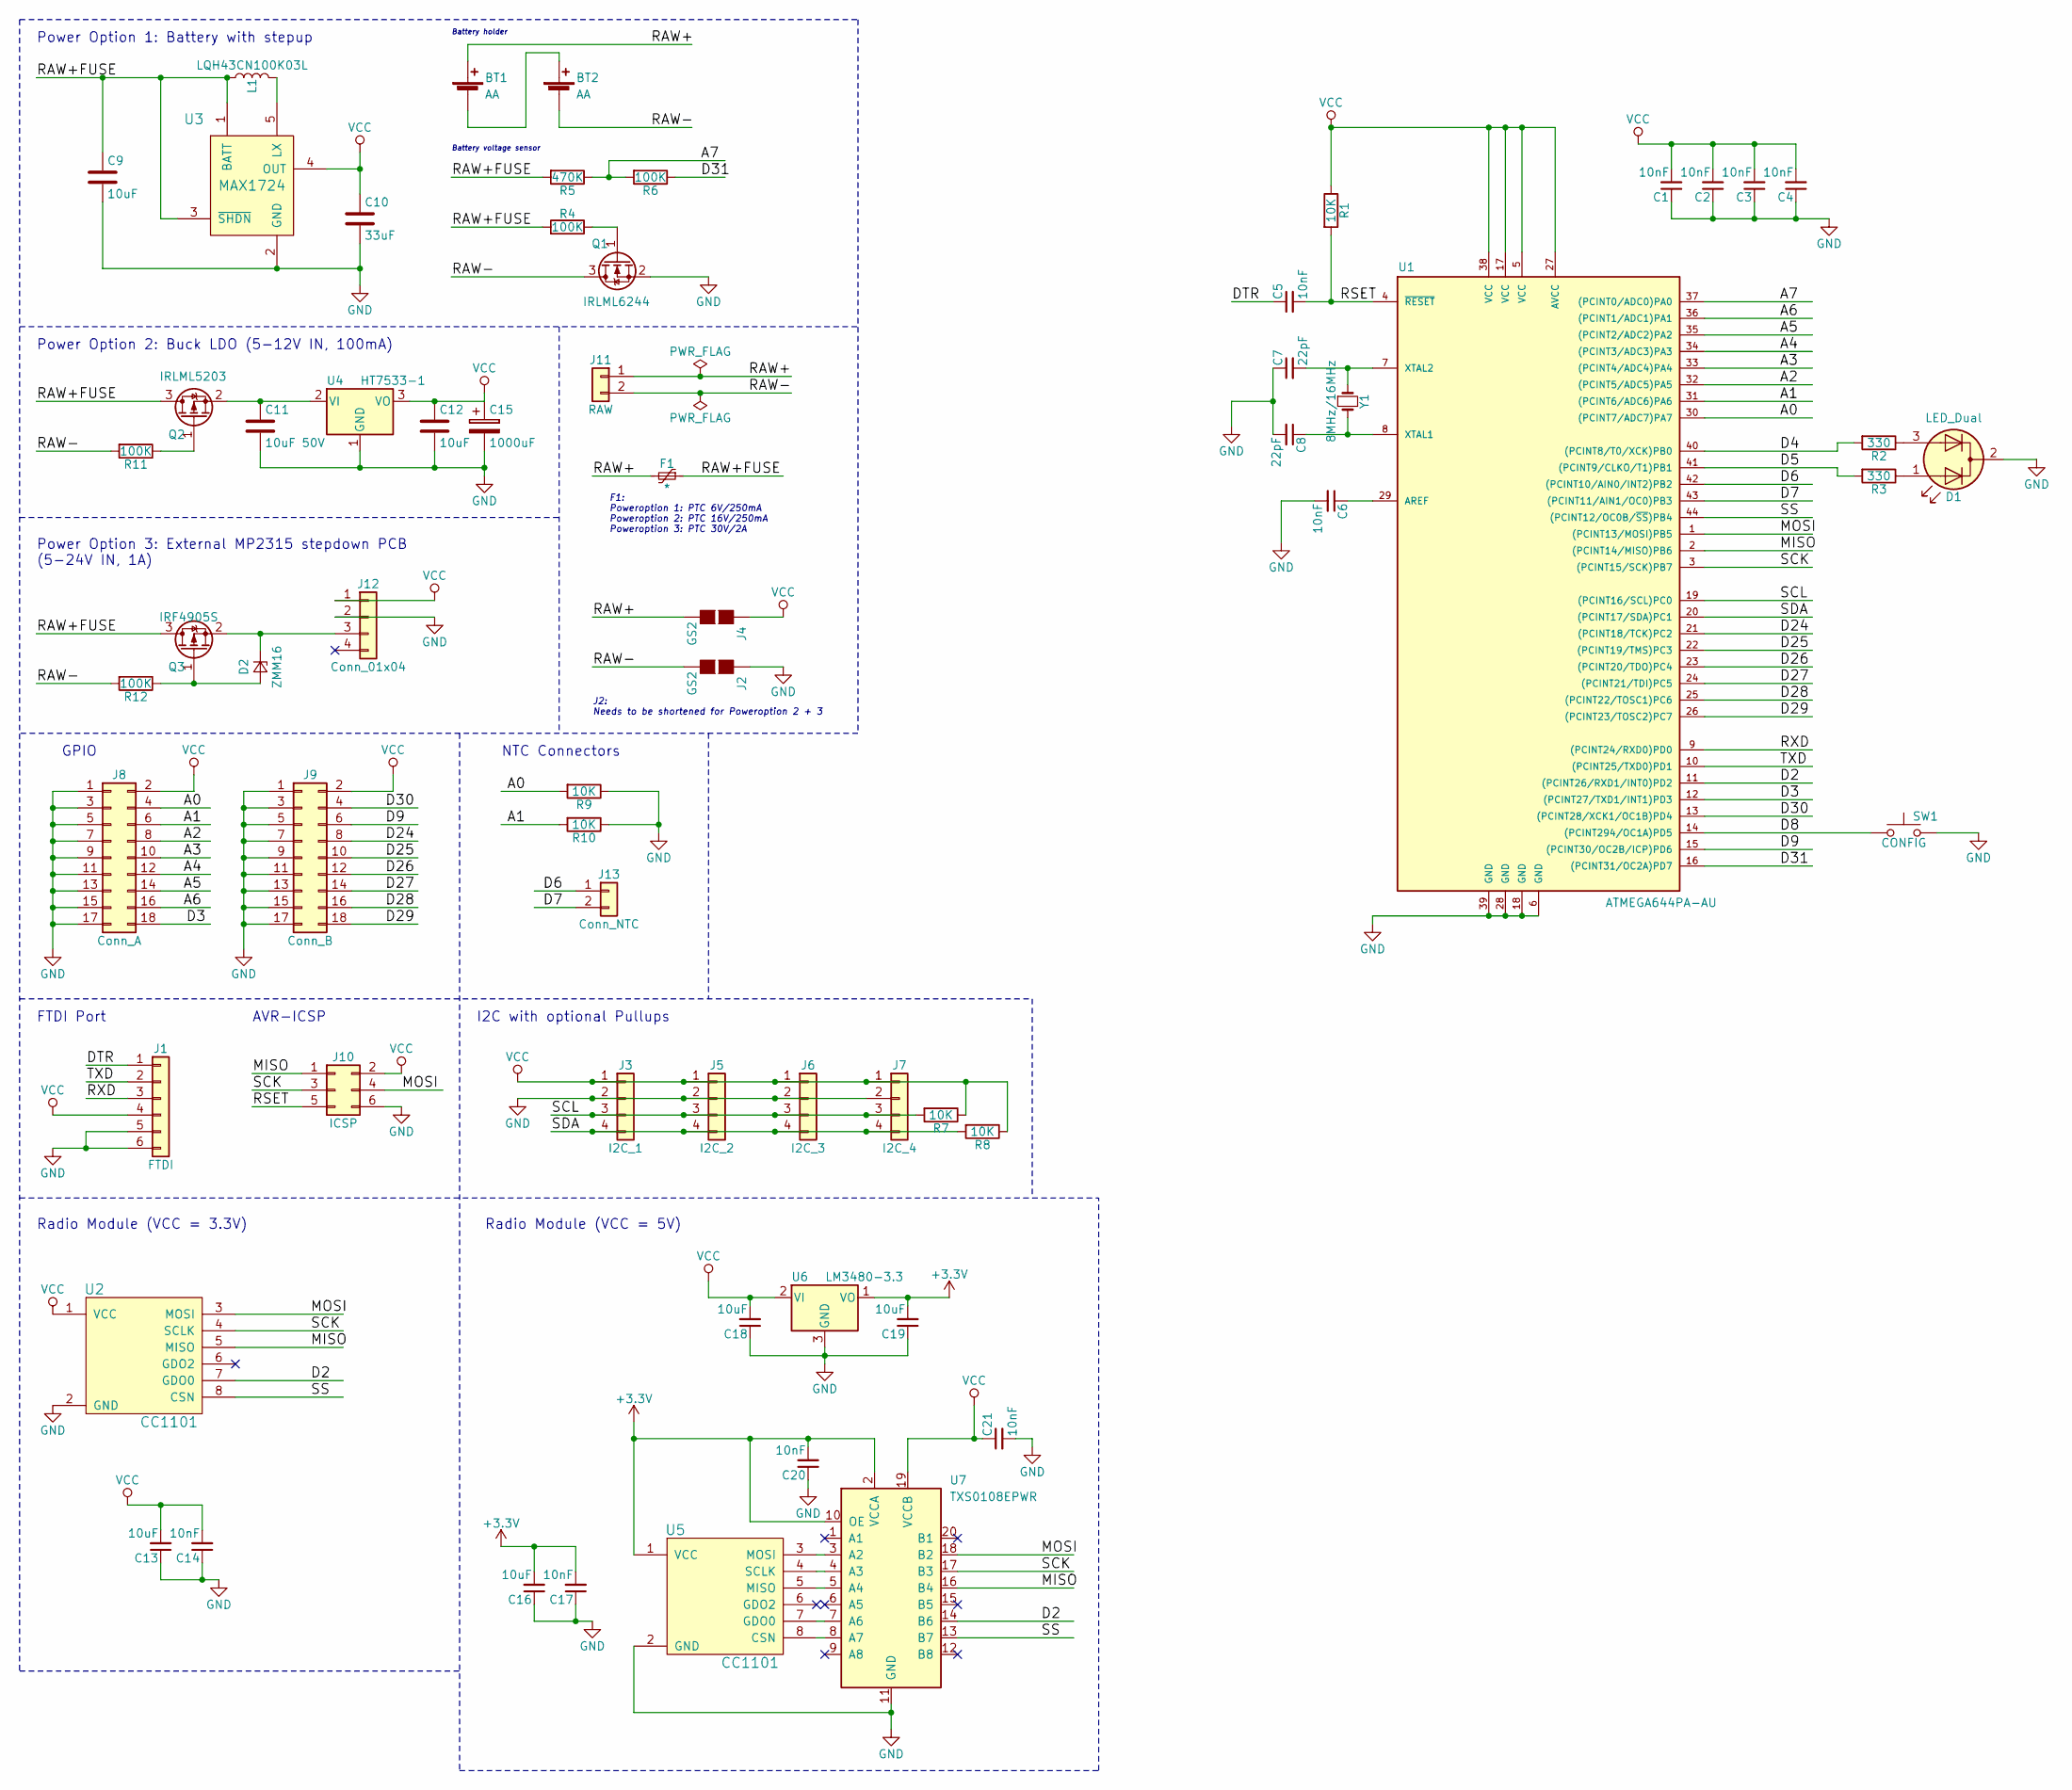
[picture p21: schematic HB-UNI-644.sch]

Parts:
BT1, BT2: AA; BATTERY_HOLDER_GOOBAY_AA
C1, C2, C3, C4, C5, C6, C14, C17, C20, C21: 10nF; C_0805_HandSoldering
C7, C8: 22pF; C_0805_HandSoldering
C9, C12, C13, C16, C18, C19: 10uF; C_0805_HandSoldering
C10: 33uF; C_1206_HandSoldering
C11: 10uF 50V; C_1206_HandSoldering
C15: 1000uF; CP_Radial_D8.0mm_P3.50mm
D1: LED_Dual; LED_D3.0mm-3
D2: ZMM16; D_MiniMELF_Handsoldering
F1: *; R_1206_HandSoldering
J1: FTDI; Pin_Header_Straight_1x06_Pitch2.54mm
J2, J4: GS2
J3: I2C_1; Pin_Header_Straight_1x04_Pitch2.54mm
J5: I2C_2; Pin_Header_Straight_1x04_Pitch2.54mm
J6: I2C_3; Pin_Header_Straight_1x04_Pitch2.54mm
J7: I2C_4; Pin_Header_Straight_1x04_Pitch2.54mm
J8: Conn_A; Pin_Header_Straight_2x09_Pitch2.54mm
J9: Conn_B; Pin_Header_Straight_2x09_Pitch2.54mm
J10: ICSP; Pin_Header_Straight_2x03_Pitch2.54mm
J11: RAW; Pin_Header_Straight_1x02_Pitch2.54mm
J12: Conn_01x04; Pin_Header_Straight_1x04_Pitch2.54mm
J13: Conn_NTC; Pin_Header_Straight_2x01_Pitch2.54mm
L1: LQH43CN100K03L; L_1812_HandSoldering
Q1: IRLML6244; SOT-23_Handsoldering
Q2: IRLML5203; SOT-23_Handsoldering
Q3: IRF4905S; TO-263-2
R1, R7, R8, R9, R10: 10K; R_0805_HandSoldering
R2, R3: 330; R_0805_HandSoldering
R4, R6, R11, R12: 100K; R_0805_HandSoldering
R5: 470K; R_0805_HandSoldering
SW1: CONFIG; SW_SPST_FSMSM
U1: ATMEGA644PA-AU; TQFP-44_10x10mm_Pitch0.8mm
U2, U5: CC1101
U3: MAX1724; TSOT-23-5_HandSoldering
U4: HT7533-1; SOT-89-3_Handsoldering
U6: LM3480-3.3; SOT-23
U7: TXS0108EPWR; TSSOP-20_4.4x6.5mm_Pitch0.65mm
Y1: 8MHz/16MHz; Crystal_HC49-U_Vertical

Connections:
+3V3: C16.2, C17.2, C19.2, C20.2, U5.1 (VCC), U6.1 (VO), U7.2 (VCCA), U7.10 (OE)
/A0: J8.4, R9.2, U1.30 ((PCINT7/ADC7)PA7)
/A1: J8.6, R10.2, U1.31 ((PCINT6/ADC6)PA6)
/A2: J8.8, U1.32 ((PCINT5/ADC5)PA5)
/A3: J8.10, U1.33 ((PCINT4/ADC4)PA4)
/A4: J8.12, U1.34 ((PCINT3/ADC3)PA3)
/A5: J8.14, U1.35 ((PCINT2/ADC2)PA2)
/A6: J8.16, U1.36 ((PCINT1/ADC1)PA1)
/A7: R5.1, R6.2, U1.37 ((PCINT0/ADC0)PA0)
/D2: U1.11 ((PCINT26/RXD1/INT0)PD2), U2.7 (GDO0), U7.14 (B6)
/D3: J8.18, U1.12 ((PCINT27/TXD1/INT1)PD3)
/D4: R2.2, U1.40 ((PCINT8/T0/XCK)PB0)
/D5: R3.2, U1.41 ((PCINT9/CLKO/T1)PB1)
/D6: J13.1, U1.42 ((PCINT10/AIN0/INT2)PB2)
/D7: J13.2, U1.43 ((PCINT11/AIN1/OC0)PB3)
/D8: SW1.1, U1.14 ((PCINT294/OC1A)PD5)
/D9: J9.6, U1.15 ((PCINT30/OC2B/ICP)PD6)
/D24: J9.8, U1.21 ((PCINT18/TCK)PC2)
/D25: J9.10, U1.22 ((PCINT19/TMS)PC3)
/D26: J9.12, U1.23 ((PCINT20/TDO)PC4)
/D27: J9.14, U1.24 ((PCINT21/TDI)PC5)
/D28: J9.16, U1.25 ((PCINT22/TOSC1)PC6)
/D29: J9.18, U1.26 ((PCINT23/TOSC2)PC7)
/D30: J9.4, U1.13 ((PCINT28/XCK1/OC1B)PD4)
/D31: R6.1, U1.16 ((PCINT31/OC2A)PD7)
/DTR: C5.1, J1.1
/MISO: J10.1, U1.2 ((PCINT14/MISO)PB6), U2.5 (MISO), U7.16 (B4)
/MOSI: J10.4, U1.1 ((PCINT13/MOSI)PB5), U2.3 (MOSI), U7.18 (B2)
/RAW+: BT1.1 (+), F1.2, J4.2 (G2), J11.1
/RAW+FUSE: C9.1, F1.1, L1.1, Q2.3 (D), Q3.3 (D), R4.2, R5.2, U3.1 (BATT), U3.3 (~SHDN)
/RAW-: BT2.2 (-), J2.2 (G2), J11.2, Q1.3 (D), R11.2, R12.2
/RSET: C5.2, J10.5, R1.2, U1.4 (~RESET)
/RXD: J1.3, U1.9 ((PCINT24/RXD0)PD0)
/SCK: J10.3, U1.3 ((PCINT15/SCK)PB7), U2.4 (SCLK), U7.17 (B3)
/SCL: J3.3, J5.3, J6.3, J7.3, R7.2, U1.19 ((PCINT16/SCL)PC0)
/SDA: J3.4, J5.4, J6.4, J7.4, R8.2, U1.20 ((PCINT17/SDA)PC1)
/SS: U1.44 ((PCINT12/OC0B/~SS~)PB4), U2.8 (CSN), U7.13 (B7)
/TXD: J1.2, U1.10 ((PCINT25/TXD0)PD1)
GND: C1.1, C2.1, C3.1, C4.1, C6.2, C7.1, C8.2, C9.2, C10.2, C11.2, C12.2, C13.1, C14.1, C15.2, C16.1, C17.1, C18.1, C19.1, C20.1, C21.2, D1.2 (K), J1.5, J1.6, J2.1 (G1), J3.2, J5.2, J6.2, J7.2, J8.1, J8.3, J8.5, J8.7, J8.9, J8.11, J8.13, J8.15, J8.17, J9.1, J9.3, J9.5, J9.7, J9.9, J9.11, J9.13, J9.15, J9.17, J10.6, J12.2, Q1.2 (S), R9.1, R10.1, SW1.2, U1.6 (GND), U1.18 (GND), U1.28 (GND), U1.39 (GND), U2.2 (GND), U3.2 (GND), U4.1 (GND), U5.2 (GND), U6.3 (GND), U7.11 (GND)
unnamed: BT1.2 (-), BT2.1 (+)
unnamed: C6.1, U1.29 (AREF)
unnamed: C7.2, U1.7 (XTAL2), Y1.1
unnamed: C8.1, U1.8 (XTAL1), Y1.2
unnamed: C11.1, Q2.2 (S), U4.2 (VI)
unnamed: D1.1 (A1), R3.1
unnamed: D1.3 (A2), R2.1
unnamed: D2.1 (K), J12.3, Q3.2 (S)
unnamed: D2.2 (A), Q3.1 (G), R12.1
unnamed: L1.2, U3.5 (LX)
unnamed: Q1.1 (G), R4.1
unnamed: Q2.1 (G), R11.1
unnamed: U5.3 (MOSI), U7.3 (A2)
unnamed: U5.4 (SCLK), U7.4 (A3)
unnamed: U5.5 (MISO), U7.5 (A4)
unnamed: U5.7 (GDO0), U7.7 (A6)
unnamed: U5.8 (CSN), U7.8 (A7)
VCC: C1.2, C2.2, C3.2, C4.2, C10.1, C12.1, C13.2, C14.2, C15.1, C18.2, C21.1, J1.4, J3.1, J4.1 (G1), J5.1, J6.1, J7.1, J8.2, J9.2, J10.2, J12.1, R1.1, R7.1, R8.1, U1.5 (VCC), U1.17 (VCC), U1.27 (AVCC), U1.38 (VCC), U2.1 (VCC), U3.4 (OUT), U4.3 (VO), U6.2 (VI), U7.19 (VCCB)

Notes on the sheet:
I2C with optional Pullups
AVR-ICSP
FTDI Port
GPIO
NTC Connectors
Power Option 1: Battery with stepup
Power Option 2: Buck LDO (5-12V IN, 100mA)
Battery holder
Battery voltage sensor
Power Option 3: External MP2315 stepdown PCB (5-24V IN, 1A)
F1: Poweroption 1: PTC 6V/250mA Poweroption 2: PTC 16V/250mA Poweroption 3: PTC 30V/2A
J2: Needs to be shortened for Poweroption 2 + 3
Radio Module (VCC = 3.3V)
Radio Module (VCC = 5V)

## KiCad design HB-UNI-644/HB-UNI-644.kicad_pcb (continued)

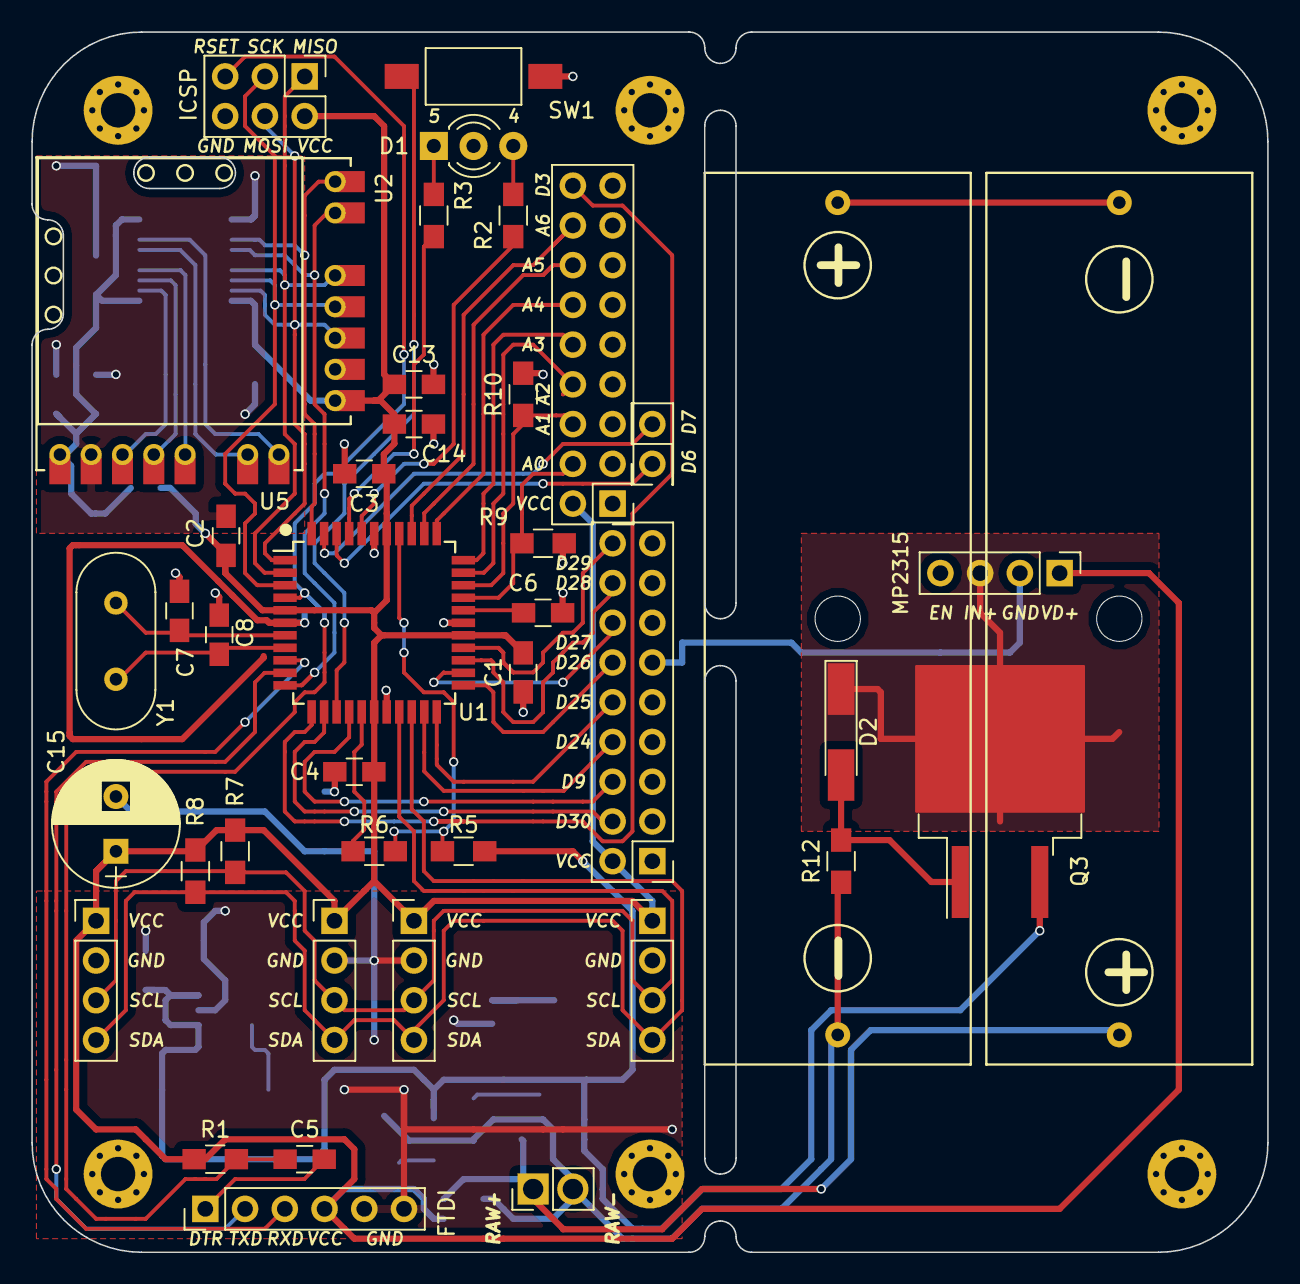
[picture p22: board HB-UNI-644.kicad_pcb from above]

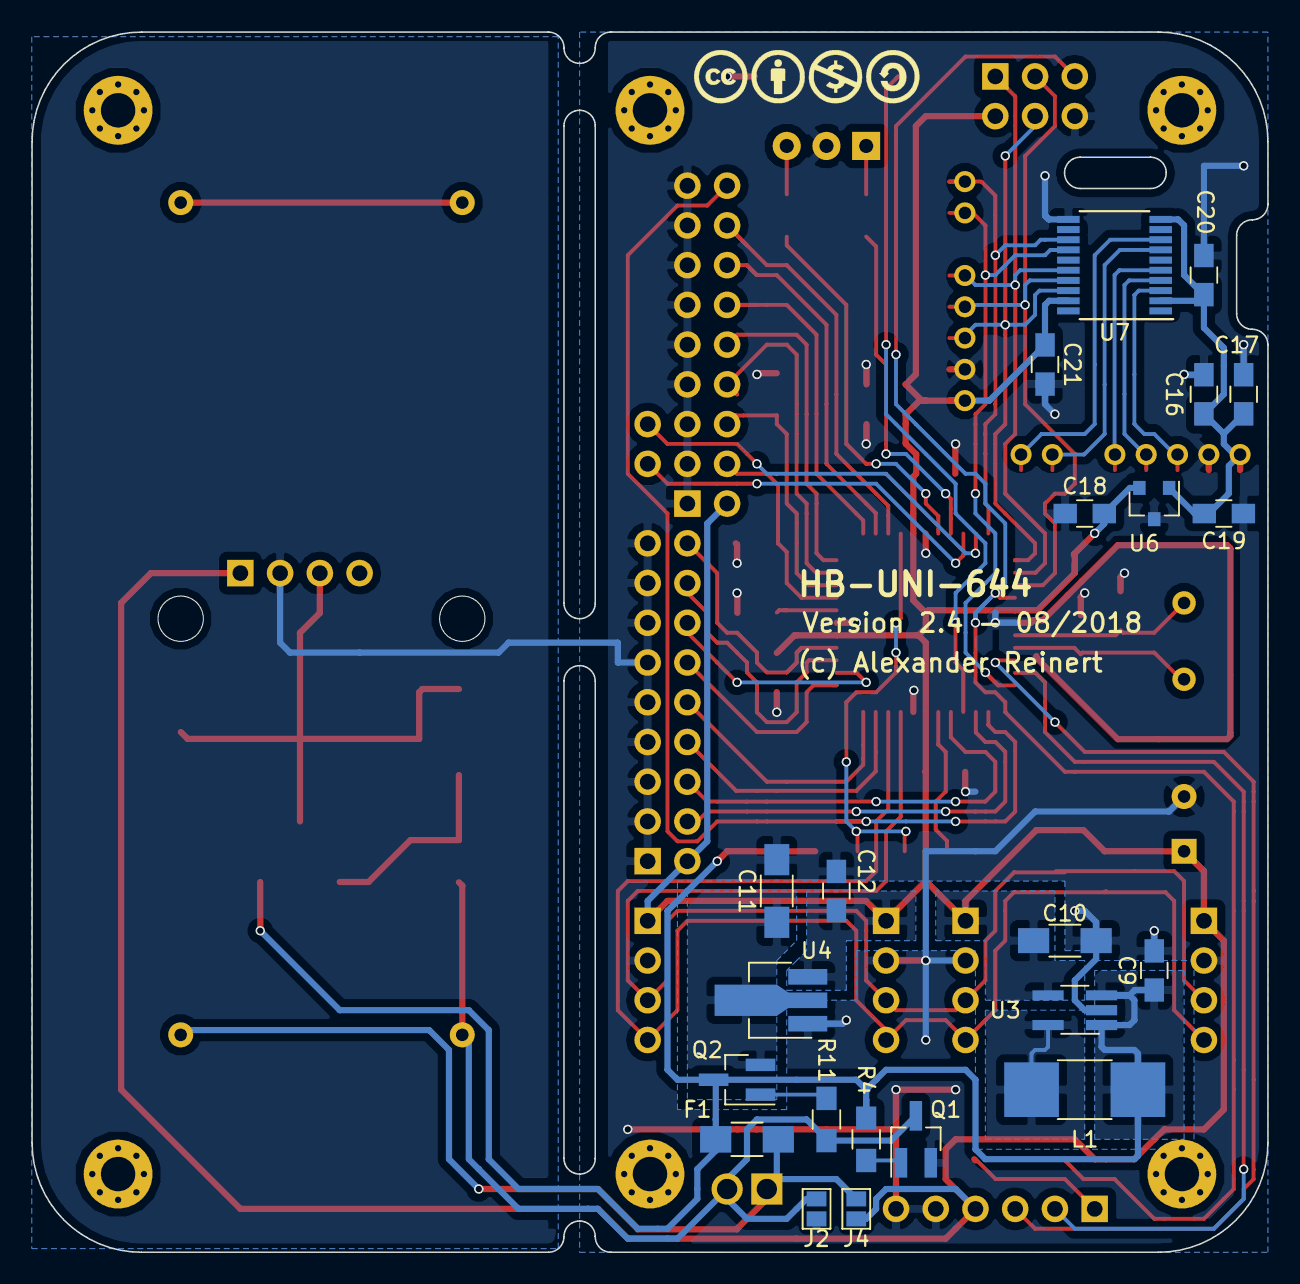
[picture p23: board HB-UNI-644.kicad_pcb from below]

Board: 2 copper layers, 79.0 x 78.0 mm, 64 parts (22 on the bottom side), 57 nets.

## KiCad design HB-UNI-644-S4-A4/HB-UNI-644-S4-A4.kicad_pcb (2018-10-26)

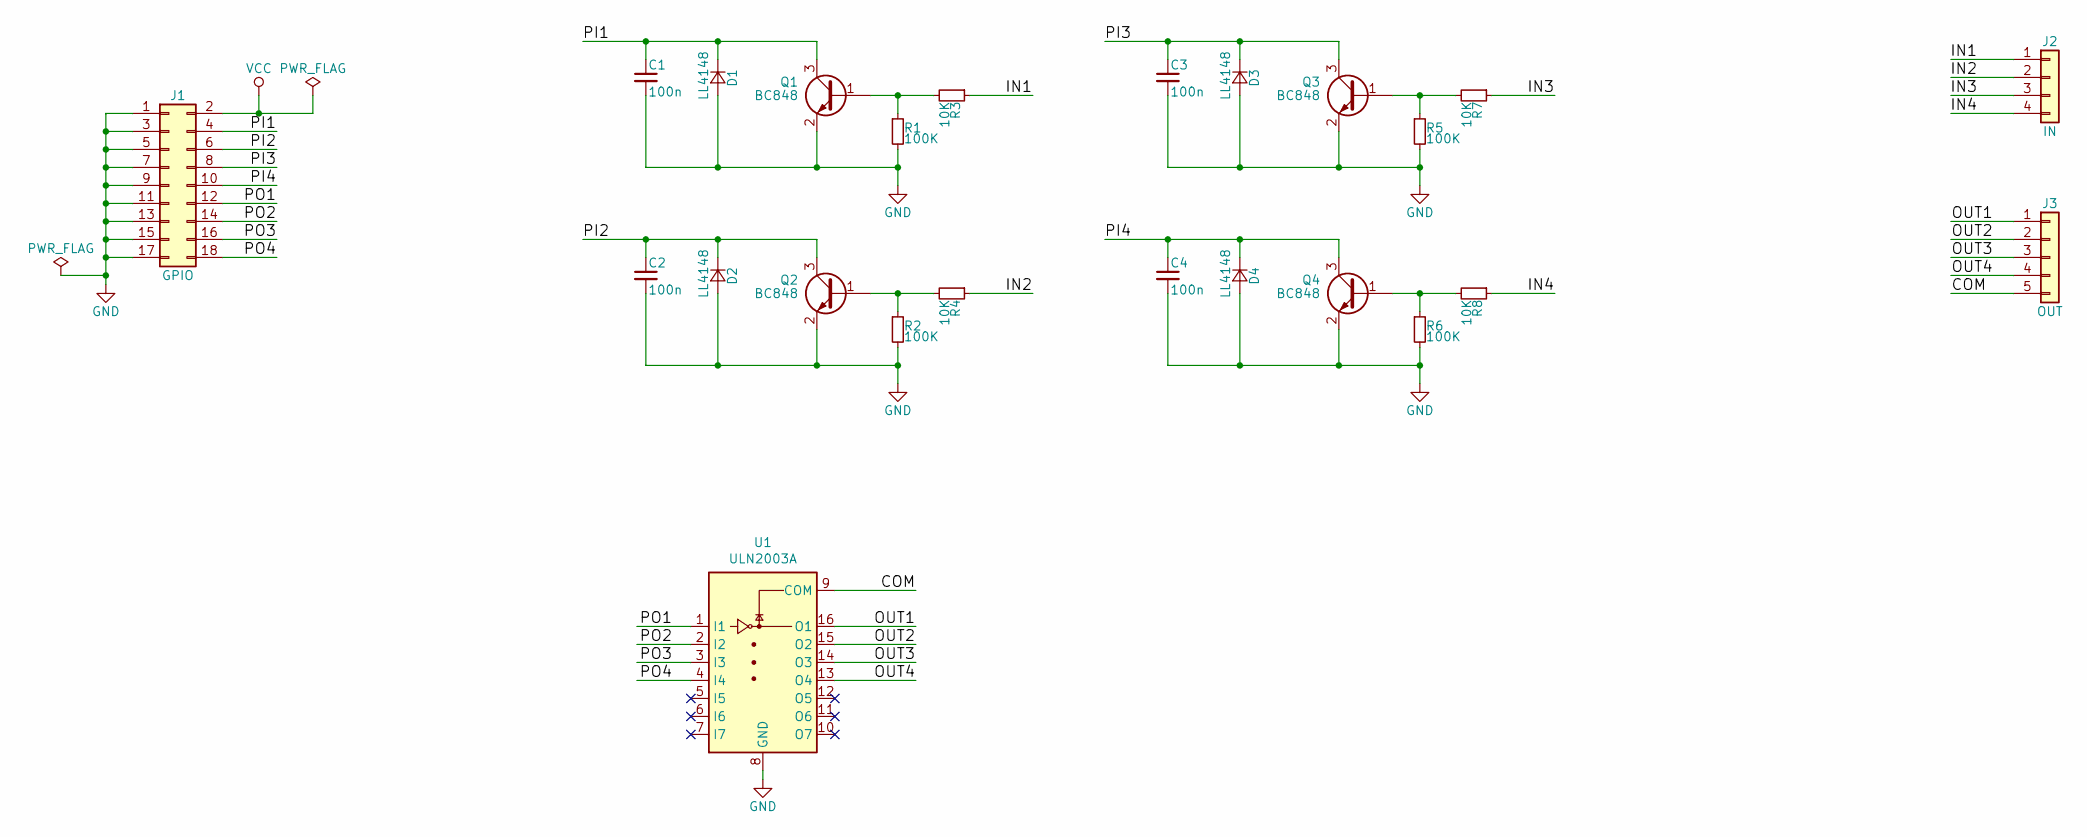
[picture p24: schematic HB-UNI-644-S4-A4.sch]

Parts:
C1, C2, C3, C4: 100n; C_0805_HandSoldering
D1, D2, D3, D4: LL4148; D_MiniMELF
J1: GPIO; Pin_Header_Straight_2x09_Pitch2.54mm
J2: IN; Molex_SPOX-5267_22-03-5045_04x2.54mm_Straight
J3: OUT; Molex_SPOX-5267_22-03-5055_05x2.54mm_Straight
Q1, Q2, Q3, Q4: BC848; SOT-23
R1, R2, R5, R6: 100K; R_0805_HandSoldering
R3, R4, R7, R8: 10K; R_0805_HandSoldering
U1: ULN2003A; SOIC-16_3.9x9.9mm_Pitch1.27mm

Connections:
/COM: J3.5, U1.9 (COM)
/IN1: J2.1, R3.1
/IN2: J2.2, R4.1
/IN3: J2.3, R7.1
/IN4: J2.4, R8.1
/OUT1: J3.1, U1.16 (O1)
/OUT2: J3.2, U1.15 (O2)
/OUT3: J3.3, U1.14 (O3)
/OUT4: J3.4, U1.13 (O4)
/PI1: C1.1, D1.1 (K), J1.4, Q1.3 (C)
/PI2: C2.1, D2.1 (K), J1.6, Q2.3 (C)
/PI3: C3.1, D3.1 (K), J1.8, Q3.3 (C)
/PI4: C4.1, D4.1 (K), J1.10, Q4.3 (C)
/PO1: J1.12, U1.1 (I1)
/PO2: J1.14, U1.2 (I2)
/PO3: J1.16, U1.3 (I3)
/PO4: J1.18, U1.4 (I4)
GND: C1.2, C2.2, C3.2, C4.2, D1.2 (A), D2.2 (A), D3.2 (A), D4.2 (A), J1.1, J1.3, J1.5, J1.7, J1.9, J1.11, J1.13, J1.15, J1.17, Q1.2 (E), Q2.2 (E), Q3.2 (E), Q4.2 (E), R1.2, R2.2, R5.2, R6.2, U1.8 (GND)
unnamed: Q1.1 (B), R1.1, R3.2
unnamed: Q2.1 (B), R2.1, R4.2
unnamed: Q3.1 (B), R5.1, R7.2
unnamed: Q4.1 (B), R6.1, R8.2
VCC: J1.2

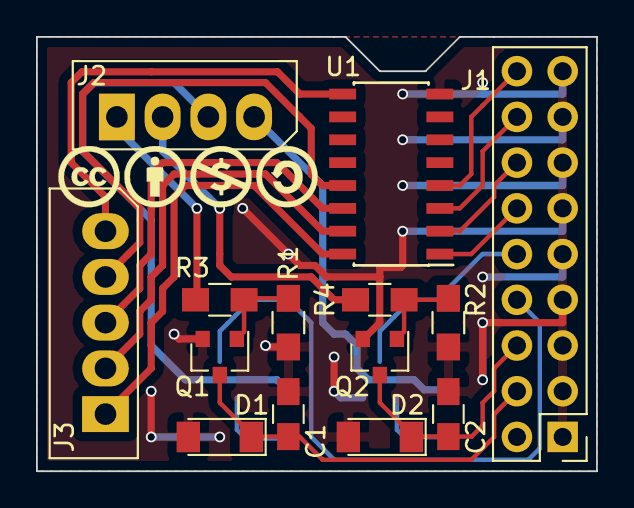
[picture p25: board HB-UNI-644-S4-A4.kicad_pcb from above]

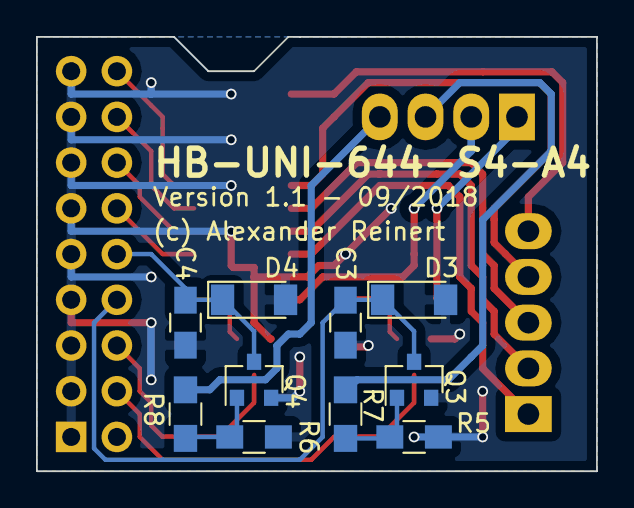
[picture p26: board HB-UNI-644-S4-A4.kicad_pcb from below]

Board: 2 copper layers, 31.1 x 24.1 mm, 24 parts (10 on the bottom side), 22 nets.

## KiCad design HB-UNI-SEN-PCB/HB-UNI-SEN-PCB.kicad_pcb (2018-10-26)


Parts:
D1: LED; LED_D3.0mm
J0: BATT; Pin_Header_Straight_1x02_Pitch2.54mm
J1: I2C_1; Pin_Header_Straight_1x04_Pitch2.54mm
J2: I2C_2; Pin_Header_Straight_1x04_Pitch2.54mm
J3: A0; Pin_Header_Straight_1x03_Pitch2.54mm
J4: A1; Pin_Header_Straight_1x03_Pitch2.54mm
J5: A2; Pin_Header_Straight_1x02_Pitch2.54mm
J6: A3; Pin_Header_Straight_1x02_Pitch2.54mm
J7: PROG; Pin_Header_Straight_1x04_Pitch2.54mm
R1: 470; R_Axial_DIN0207_L6.3mm_D2.5mm_P10.16mm_Horizontal
R2, R3: 10K; R_Axial_DIN0207_L6.3mm_D2.5mm_P10.16mm_Horizontal
SW1: CONFIG_BUTTON; SW_PUSH_6mm_h5mm
U1: ArduinoProMini
U2: CC1101

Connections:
+3V3: J0.1, J1.1, J2.1, U1.9 (VCC), U2.1 (VCC)
/A0: J3.1, R2.1, U1.5 (A0)
/A1: J4.1, R3.1, U1.6 (A1)
/A2: J5.1, U1.7 (A2)
/A3: J6.1, U1.8 (A3)
/D2: U1.17 (2), U2.7 (GDO0)
/D5: J4.3, U1.20 (5)
/D6: J3.3, U1.21 (6)
/MISO: J7.3, U1.3 (12/MISO), U2.5 (MISO)
/MOSI: J7.1, U1.2 (11/MOSI), U2.3 (MOSI)
/RSET: J7.4, U1.10 (RSET)
/SCK: J7.2, U1.4 (13/SCK), U2.4 (SCLK)
/SCL: J1.3, J2.3, U1.26 (A5/SCL)
/SDA: J1.4, J2.4, U1.25 (A4/SDA)
/SS: U1.1 (10/SS), U2.8 (CSN)
GND: D1.1 (K), J0.2, J1.2, J2.2, J3.2, J4.2, J5.2, J6.2, R2.2, R3.2, SW1.2, U1.11 (GND), U1.16 (GND), U2.2 (GND)
unnamed: D1.2 (A), R1.1
unnamed: R1.2, U1.19 (4)
unnamed: SW1.1, U1.23 (8)


Board: 2 copper layers, 44.4 x 30.5 mm, 15 parts (0 on the bottom side), 19 nets.

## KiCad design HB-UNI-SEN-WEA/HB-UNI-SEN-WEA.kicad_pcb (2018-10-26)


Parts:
C1: 1nF; C_Disc_D3.8mm_W2.6mm_P2.50mm
C2: 10uF; CP_Radial_D4.0mm_P1.50mm
J1: PWR; Molex_SPOX-5267_22-03-5025_02x2.54mm_Straight
J2: I2C_1; Molex_SPOX-5267_22-03-5045_04x2.54mm_Straight
J3: I2C_2; Molex_SPOX-5267_22-03-5045_04x2.54mm_Straight
J4: I2C_3; Molex_SPOX-5267_22-03-5045_04x2.54mm_Straight
J5: ANEMOMETER; Molex_SPOX-5267_22-03-5025_02x2.54mm_Straight
J6: RAIN_VOL; Molex_SPOX-5267_22-03-5025_02x2.54mm_Straight
J7: WIND_DIR; Molex_SPOX-5267_22-03-5025_02x2.54mm_Straight
J8: RAIN_SENS; Molex_SPOX-5267_22-03-5045_04x2.54mm_Straight
J9: LIGHTNING; Molex_SPOX-5267_22-03-5075_07x2.54mm_Straight
Q1: MPSA13; TO-92_Inline_Narrow_Oval
R1: 10K; R_Axial_DIN0207_L6.3mm_D2.5mm_P10.16mm_Horizontal
R2: 100K; R_Axial_DIN0207_L6.3mm_D2.5mm_P10.16mm_Horizontal
SW1: CONFIG_BUTTON; SW_PUSH_6mm_h5mm
U1: ArduinoProMini
U2: CC1101

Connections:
+3V3: C2.1, J2.1, J3.1, J4.1, J9.1, U1.9 (VCC), U2.1 (VCC)
/A2: J7.1, U1.7 (A2)
/A3: C1.2, R2.1, U1.8 (A3)
/D2: U1.17 (2), U2.7 (GDO0)
/D3: J9.4, U1.18 (3)
/D4: R2.2, U1.19 (4)
/D5: J5.1, U1.20 (5)
/D6: J6.1, U1.21 (6)
/D7: J9.3, U1.22 (7)
/D9: R1.2, U1.24 (9)
/MISO: J9.7, U1.3 (12/MISO), U2.5 (MISO)
/MOSI: J9.5, U1.2 (11/MOSI), U2.3 (MOSI)
/SCK: J9.6, U1.4 (13/SCK), U2.4 (SCLK)
/SCL: J2.3, J3.3, J4.3, U1.26 (A5/SCL)
/SDA: J2.4, J3.4, J4.4, U1.25 (A4/SDA)
/SS: U1.1 (10/SS), U2.8 (CSN)
GND: C2.2, J1.2, J2.2, J3.2, J4.2, J5.2, J6.2, J7.2, J8.4, J9.2, Q1.1 (E), SW1.2, U1.11 (GND), U1.16 (GND), U2.2 (GND)
unnamed: C1.1, J8.3
unnamed: J8.2, Q1.3 (C)
unnamed: Q1.2 (B), R1.1
unnamed: SW1.1, U1.23 (8)
VCC: J1.1, J8.1, U1.12 (RAW)


Board: 2 copper layers, 45.7 x 45.7 mm, 17 parts (0 on the bottom side), 22 nets.

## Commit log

2018-04-24 Added Schematic PDF and PCB images
2018-04-25 Optimized footprints
    [HB-UNI-SEN-BATT-B.Cu.gbr, HB-UNI-SEN-BATT-B.Mask.gbr, HB-UNI-SEN-BATT-B.SilkS.gbr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]
2018-05-03 Added reverse polarity protection
    [HB-UNI-SEN-BATT-B.Cu.gbr, HB-UNI-SEN-BATT-B.Mask.gbr, HB-UNI-SEN-BATT-B.SilkS.gbr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]
2018-05-03 Added HB-UNI-SEN-O
    [HB-UNI-SEN-O-B.Cu.gbr, HB-UNI-SEN-O-B.Mask.gbr, HB-UNI-SEN-O-B.SilkS.gbr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]
2018-05-08 Optimized drill hole size for IRLU024N
    [HB-UNI-SEN-BATT-B.Cu.gbr, HB-UNI-SEN-BATT-B.Mask.gbr, HB-UNI-SEN-BATT-B.SilkS.gbr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]
2018-06-16 Added new PCB HB-UNI-644, removed unfinished HB-UNI-SEN-O
    [HB-UNI-644-B.Cu.gbr, HB-UNI-644-B.Mask.gbr, HB-UNI-644-B.SilkS.gbr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]
2018-06-17 Added hint to schematic which mosfet to use on HB-UNI-644
    [HB-UNI-644.sch]
2018-07-29 Revision 2 of HB-UNI-644
    [HB-UNI-644-B.Cu.gbr, HB-UNI-644-B.Mask.gbr, HB-UNI-644-B.SilkS.gbr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]
2018-07-30 Fixed Gerber files of HB-UNI-SEN-BATT (fixes #2)
    Fixed README of HB-UNI-BATT (fixes #1)
    Optimized Silkscreen of HB-UNI-644
    [HB-UNI-644-B.Cu.gbr, HB-UNI-644-B.Mask.gbr, HB-UNI-644-B.SilkS.gbr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]
2018-07-31 Fixed Stepdown module on HB-UNI-644
    [HB-UNI-644-B.Cu.gbr, HB-UNI-644-B.Mask.gbr, HB-UNI-644-B.SilkS.gbr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]
2018-08-02 Relicened under CC BY-ND-SA
    [HB-UNI-644-B.Cu.gbr, HB-UNI-644-B.Mask.gbr, HB-UNI-644-B.SilkS.gbr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]
2018-08-08 Added HB-UNI-SEN-WEA
    [HB-UNI-SEN-WEA-B.Cu.gbr, HB-UNI-SEN-WEA-B.Mask.gbr, HB-UNI-SEN-WEA-B.SilkS.gbr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]
2018-08-16 Fixed Silkscreen of D6 and D7 on HB-UNI-644
    [HB-UNI-644-B.Cu.gbr, HB-UNI-644-B.Mask.gbr, HB-UNI-644-B.SilkS.gbr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]
2018-10-26 * Switched to Kicad 5 * Added HB-UNI-644-S4-A4 addon Board
    [HB-UNI-644-S4-A4-B.Cu.gbr, HB-UNI-644-S4-A4-B.Mask.gbr, HB-UNI-644-S4-A4-B.SilkS.gbr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]
2021-07-29 Added HB-RF-USB
    [HB-RF-USB-B.Cu.gbr, HB-RF-USB-B.Mask.gbr, HB-RF-USB-B.SilkS.gbr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]
2021-07-29 - Update to Kicad 5 symbol and footprint libs
    - Use different Micro USB Connector for better mechanical stability
    [HB-RF-USB-B_Cu.gbr, HB-RF-USB-B_Mask.gbr, HB-RF-USB-B_SilkS.gbr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]
2021-07-29 Added HB-RF-USB-2
    [HB-RF-USB-2-B_Cu.gbr, HB-RF-USB-2-B_Mask.gbr, HB-RF-USB-2-B_Paste.gbr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]
2021-07-29 Added HB-RF-ETH
    [HB-RF-ETH-B_Cu.gbr, HB-RF-ETH-B_Mask.gbr, HB-RF-ETH-B_Paste.gbr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]

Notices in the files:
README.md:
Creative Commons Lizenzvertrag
